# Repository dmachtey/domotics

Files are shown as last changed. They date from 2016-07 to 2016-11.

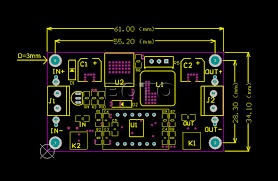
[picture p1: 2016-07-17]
electronic/board/dc-dc-converter.jpeg

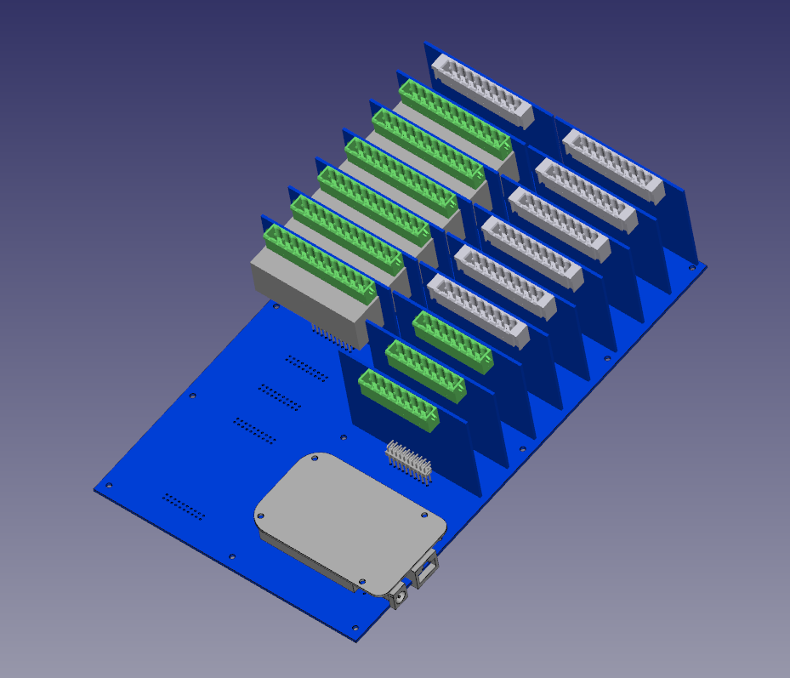
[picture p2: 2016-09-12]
pictures/3d/3d_boards_model1.png

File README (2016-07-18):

-*- mode: org -*-

* This is another domotics project
    - it is based on Beaglebone Black
    - Its able to control up to 64 Inputs or Outputs in blocks of 4
    - I've developed a main board were is possible to plug up to 16
      4-inputs or 4-outputs boards (4 GPIOs). All of them are
      optocoupled.
      - I've already developed a 4-relays board and 4-transistors
        board wich can control lights intensity by PWM and also
        4-imputs board
    - The power board can be connected to a battery and detect a mains
      failure
    - It's already able to comunicate with Openhab, an android and ios
      application
    - It's in production now since April 8th 2016 in my home
    - There is also 2 more slots with 3 and 4 analogs inputs, I'm
      planing to sense the battery level and natural light level.
    - Into one of the 16 slots I'm planing to connect some DS18B20 (up
      to 10 can be connected to one gpio) to sense the rooms
      temperatures.

* This is my first project to be published
  I'm trying to sort thins out to make them easier to understan

  I will re-write some of c++ objects to make them clear to understand

* This is what is now running
  - A full functional project is in production at my home have a look
    at the pictures folder
  - Now I'm controlling 5 PWM circuits for lights
  - I've also 5 inputs
  - All outputs are controlled by Openhab web application from LAN/WAN

* How to test this project
  - Get a Beagle bone black with Linux running
  - do :: apt-get install build-essential
  - do :: apt-get install linux-image-3.8.13-bone68 device-tree-compiler
    - to be able to compile new capes, they are needed to manage GPIOs
  - compile the cape /domotics/capes/half-in-half-pru.dts
    - copy the compiled code to /lib/firmware/
  - get yours electronics ready and connected to one of the gpio used
    on "on-production/test-pwm.cpp" like "GPIO 27"
  - Connect and input switch at "GPIO 4"
  - copy the contemns of "/domotics/on-production" to /pru2 at BBB
  - run /pru2/start.sh
  - Your led should get PWM controlled with the switch

  - Optional:
    If you want to run it with openhab for remote controll
    - Install libc-ares-dev uuid-dev libwrap0-dev libssl-dev needed by
      mosquitto library
    - Install mosquitto it can be downloaded here: http://mosquitto.org/download/
  - Install openhab, instructions at it's site: http://openhab.org/
    - copy /domotics/root/* to "/" at BBB
  - Install an configure your openhab to point to your BBB ip as http://BBBip:8080

* Project files
  - /domotics/docs/files-strucure.org

* Contact information
  - Damian Machtey
  - dmachtey at gmail com

* License
  The code and hardware is being released under GPL v3.

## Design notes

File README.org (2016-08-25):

* Why this project is different?
  - I haven't found any complete project like this, I mean a general
    purpose (home) automation project with a full developed hardware
    and software.
* This is a domotics project sw&hw (or general controller)
    - The goals of this project are:
      - to be affordable (price/(outputs + inputs)), every thing is
        hardwired (not for every one)
      - reliability (every thing have to be easy to replace, my wife
        has to be able to do it)
      - flexibility (gotten by division of GPIOs in groups of 4)
    - it is based on Beaglebone Black (BBB)
    - Its able to control up to 64 Inputs or Outputs in blocks of 4
    - I've developed a main board were is possible to plug up to 16
      4-inputs or 4-outputs boards (4 GPIOs). All of them are
      optocoupled.
      - I've already developed a 4-relays board and 4-transistors
        board wich can control lights intensity by PWM and also
        4-imputs board
    - The power board can be connected to a battery and detect a mains
      failure
    - It's already able to communicate with Openhab, an android and ios
      application, or whatever application that support MQTT protocol
    - It's in production now since April 8th 2016 in my home
    - There are also 2 more slots with 3 and 4 analogs inputs, I'm
      planing to sense the battery level and natural light level.
    - Into one of the 16 slots I'm planing to connect some DS18B20 (up
      to 10 can be connected to one gpio) to sense the rooms
      temperatures.
* This is my first project to be published
  - I'm trying to sort thins out to make them easier to understand
  - I will re-write some of c++ objects to make them more clear
  - Many directories still need to be populated,

* This is what is now running
  - A full functional project is in production at my home. Have a look
    at the pictures folder for images
  - Now I'm controlling 5 PWM circuits for lights
  - I've also 6 inputs
  - All outputs are controlled by Openhab web application from LAN/WAN

* How to test this project
  - Get a Beagle bone black with Linux running
  - to be able to compile c++ and new capes, they are needed to manage GPIOs
    - do =apt-get install build-essential=
    - do =apt-get install linux-image-3.8.13-bone68
      device-tree-compiler am335x-pru-package=
    - do =apt-get install libmosquitto-dev libmosquittopp-dev mosquitto mosquitto-clients=
  - compile the cape /domotics/capes/half-in-half-out.dts by =make=
    - install by =make install=
  - get yours electronics ready and connected to one of the gpio used
    on "running/test-pwm.cpp" like "GPIO 27"
  - Connect and input switch at "GPIO 4"
  - copy the contents of "/domotics/running" to /pru2 at BBB
  - run =make=
  - run =/pru2/start.sh=
  - Your led should get PWM controlled with the switch

  - Optional:
  - Install openhab, instructions at it's site: http://openhab.org/
    - copy /domotics/root/* to "/" at BBB
  - Install an configure your openhab to point to your BBB ip as http://BBBip:8080

* Project files
  - [[./docs/files-strucure.org]]

* Contributors
  - Every one willing to contribute with this project is welcome
** Software
   - none yet
** Electronics
   - none yet
** Linux SO
   - none yet
** Others
   - none yet

* Contact information
  - Damian Machtey
  - dmachtey at gmail com

* License
  The code and hardware is being released under GPL v3.

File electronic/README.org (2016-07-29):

   *Use kitcad to open the files*

* files structure and comments (should be here)

* Scripts/other programs
  - headers-cloner.py :: was used to automatically arrange the socket
       connectors
  - FreeRouting :: was used to help ruting
    - http://www.freerouting.net/fen/viewtopic.php?f=4&t=255

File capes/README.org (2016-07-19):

* To be able to use all the 65 gpio you need to:

** Disable some capes

edit /boot/uEnv.txt and add:
#+BEGIN_EXAMPLE
         optargs=quietcapemgr.disable_partno=BB-BONELT-HDMI,BB-BONELT-HDMIN,BB-BONE-EMMC-2G
#+END_EXAMPLE

Reboot, and

if it works: you should see some thing like this:

#+BEGIN_EXAMPLE
   root@beaglebone:~# SLOTS=/sys/devices/bone_capemgr.9/slots
   root@beaglebone:~# cat $SLOTS
    0: 54:PF---
    1: 55:PF---
    2: 56:PF---
    3: 57:PF---
    4: ff:P-O-- Bone-LT-eMMC-2G,00A0,Texas Instrument,BB-BONE-EMMC-2G
    5: ff:P-O-- Bone-Black-HDMI,00A0,Texas Instrument,BB-BONELT-HDMI
    6: ff:P-O-- Bone-Black-HDMIN,00A0,Texas Instrument,BB-BONELT-HDMIN
#+END_EXAMPLE
and ther should be no "L"  before the capes lines

** Load the new cape
As an example

#+BEGIN_SRC sh
    SLOTS=/sys/devices/bone_capemgr.9/slots
    echo half-in-half-pru > $SLOTS
#+END_SRC

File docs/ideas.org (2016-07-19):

* Some ideas to add to the system
  - Voip, can be easily added with asterisk
    - door phone to answer at cellphones
    - Gateway land line to cellphones
  - Curtain control
  - Infra red to control air conditioners & others devices
  - Temperature sensors, to measure rooms temperature

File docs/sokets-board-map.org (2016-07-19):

** Main Board GPIOs map
*** Slots
| Slot # | Order | GPIO#    | Analog=0/General=1 | G1 | G2 | GPIO_NUM |       |      |   |
|--------+-------+----------+--------------------+----+----+----------+-------+------+---|
|      0 |     4 | GPIO2_14 |                  1 |  2 | 14 |       78 |       |      |   |
|      0 |     3 | GPIO0_8  |                  1 |  0 |  8 |        8 |       |      |   |
|      0 |     2 | GPIO0_9  |                  1 |  0 |  9 |        9 |       |      |   |
|      0 |     1 | GPIO0_10 |                  1 |  0 | 10 |       10 |       |      |   |
|      1 |     4 | GPIO2_6  |                  1 |  2 |  6 |       70 |       |      |   |
|      1 |     3 | GPIO2_8  |                  1 |  2 |  8 |       72 |       |      |   |
|      1 |     2 | GPIO2_10 |                  1 |  2 | 10 |       74 |       |      |   |
|      1 |     1 | GPIO2_12 |                  1 |  2 | 12 |       76 |       |      |   |
|      2 |     4 | GPIO2_13 |                  1 |  2 | 13 |       77 |       |      |   |
|      2 |     3 | GPIO2_11 |                  1 |  2 | 11 |       75 |       |      |   |
|      2 |     2 | GPIO2_9  |                  1 |  2 |  9 |       73 |       |      |   |
|      2 |     1 | GPIO2_7  |                  1 |  2 |  7 |       71 |       |      |   |
|      3 |     4 | GPIO0_11 |                  1 |  0 | 11 |       11 |       |      |   |
|      3 |     3 | GPIO2_17 |                  1 |  2 | 17 |       81 |       |      |   |
|      3 |     2 | GPIO2_16 |                  1 |  2 | 16 |       80 |       |      |   |
|      3 |     1 | GPIO2_15 |                  1 |  2 | 15 |       79 |       |      |   |
|      4 |     4 | GPIO0_23 |                  1 |  0 | 23 |       23 |       |      |   |
|      4 |     3 | GPIO1_13 |                  1 |  1 | 13 |       45 |       |      |   |
|      4 |     2 | GPIO2_5  |                  1 |  2 |  5 |       69 |       |      |   |
|      4 |     1 | GPIO2_2  |                  1 |  2 |  2 |       66 |       |      |   |
|      5 |     4 | GPIO1_2  |                  1 |  1 |  2 |       34 |       |      |   |
|      5 |     3 | GPIO1_6  |                  1 |  1 |  6 |       38 |       |      |   |
|      5 |     2 | GPIO1_7  |                  1 |  1 |  7 |       39 |       |      |   |
|      5 |     1 | GPIO1_3  |                  1 |  1 |  3 |       35 |       |      |   |
|      6 |     4 | GPIO2_3  |                  1 |  2 |  3 |       67 |       |      |   |
|      6 |     3 | GPIO2_4  |                  1 |  2 |  4 |       68 |       |      |   |
|      6 |     2 | GPIO1_12 |                  1 |  1 | 12 |       44 |       |      |   |
|      6 |     1 | GPIO0_26 |                  1 |  0 | 26 |       26 |       |      |   |
|      7 |     4 | GPIO1_14 |                  1 |  1 | 14 |       46 |       |      |   |
|      7 |     3 | GPIO2_1  |                  1 |  2 |  1 |       65 |       |      |   |
|      7 |     2 | GPIO1_31 |                  1 |  1 | 31 |       63 | UART4 |      |   |
|      7 |     1 | GPIO1_5  |                  1 |  1 |  5 |       37 |       |      |   |
|      8 |     4 | GPIO1_1  |                  1 |  1 |  1 |       33 |       |      |   |
|      8 |     3 | GPIO1_29 |                  1 |  1 | 29 |       61 |       |      |   |
|      8 |     2 | GPIO2_24 |                  1 |  2 | 24 |       88 |       |      |   |
|      8 |     1 | GPIO2_25 |                  1 |  2 | 25 |       89 |       |      |   |
|      9 |     4 | GPIO2_23 |                  1 |  2 | 23 |       87 |       |      |   |
|      9 |     3 | GPIO2_22 |                  1 |  2 | 22 |       86 |       |      |   |
|      9 |     2 | GPIO1_0  |                  1 |  1 |  0 |       32 |       |      |   |
|      9 |     1 | GPIO1_4  |                  1 |  1 |  4 |       36 |       |      |   |
|     10 |     4 | GPIO1_30 |                  1 |  1 | 30 |       62 | UART4 |      |   |
|     10 |     3 | GPIO0_22 |                  1 |  0 | 22 |       22 |       |      |   |
|     10 |     2 | GPIO0_27 |                  1 |  0 | 27 |       27 |       |      |   |
|     10 |     1 | GPIO1_15 |                  1 |  1 | 15 |       47 |       |      |   |
|     11 |     4 | GPIO1_28 |                  1 |  1 | 28 |       60 |       |      |   |
|     11 |     3 | GPIO1_18 |                  1 |  1 | 18 |       50 |       |      |   |
|     11 |     2 | GPIO1_19 |                  1 |  1 | 19 |       51 |       |      |   |
|     11 |     1 | GPIO0_4  |                  1 |  0 |  4 |        4 | I2C1  |      |   |
|     12 |     4 | GPIO0_2  |                  1 |  0 |  2 |        2 | UART2 | I2C2 |   |
|     12 |     3 | GPIO0_15 |                  1 |  0 | 15 |       15 | UART1 | I2C1 | * |
|     12 |     2 | GPIO0_14 |                  1 |  0 | 14 |       14 | UART1 | I2C1 | * |
|     12 |     1 | GPIO3_1  |                  1 |  3 | 19 |      115 |       |      |   |
|     13 |     3 | GPIO1_16 |                  1 |  1 | 16 |       48 |       |      |   |
|     13 |     2 | GPIO0_31 |                  1 |  0 | 31 |       31 |       |      |   |
|     13 |     1 | GPIO0_30 |                  1 |  0 | 30 |       30 |       |      |   |
|     13 |     4 | GPIO0_20 |                  1 |  0 | 20 |       20 |       |      |   |
|     14 |     4 | GPIO3_21 |                  1 |  3 | 21 |      117 |       |      |   |
|     14 |     3 | GPIO1_17 |                  1 |  1 | 17 |       49 |       |      |   |
|     14 |     2 | GPIO0_3  |                  1 |  0 |  3 |        3 | UART2 | I2C2 |   |
|     14 |     1 | GPIO0_5  |                  1 |  0 |  5 |        5 | I2C1  |      |   |
|     15 |     4 | GPIO3_17 |                  1 |  3 | 17 |      113 | SPI   |      |   |
|     15 |     3 | GPIO3_16 |                  1 |  3 | 16 |      112 | SPI   |      |   |
|     15 |     2 | GPIO3_14 |                  1 |  3 | 14 |      110 | SPI   |      |   |
|     15 |     1 | GPIO3_15 |                  1 |  3 | 15 |      111 | SPI   |      |   |
|     16 |     1 | AN4      |                  0 |    |    |        0 |       |      |   |
|     16 |     2 | AN6      |                  0 |    |    |        0 |       |      |   |
|     16 |     3 | AN2      |                  0 |    |    |        0 |       |      |   |
|     16 |     4 | AN0      |                  0 |    |    |        0 |       |      |   |
|     17 |     4 | AN5      |                  0 |    |    |        0 |       |      |   |
|     17 |     3 | AN3      |                  0 |    |    |        0 |       |      |   |
|     17 |     2 | AN1      |                  0 |    |    |        0 |       |      |   |

*BBB don't boot if out-board is plug on slots 0,1,2 as [2015-10-14 Wed]*

the SYSBOOT pins, which are also the LCD_DATA pins, are located on the
headers from P8:31 to P8:46. The pins are used to index the device
table from which the list of devices is extracted.Any error that
occurs in reading the value of these pins sends the ROM boot code into
a loop, waiting for the watchdog to reset the system.

These pins can be used by software after ROM execution has
completed. So, we can't have anything connected to these pins when the
ROM code is executing.

**** Other pins functions
| I2C1_SCL  | spi0_cs0      | I2C1_SCL  | ehrpwm0_synci      | gpio0[5]  | 17 |
| I2C1_SDA  | spi0_d1       | I2C1_SDA  | ehrpwm0_tripzone   | gpio0[4]  | 18 |
| UART2_TXD | spi0_d0       | I2C2_SCL  | ehrpwm0B           | gpio0[3]  | 21 |
| UART2_RXD | spi0_sclk     | I2C2_SDA  | ehrpwm0A           | gpio0[2]  | 22 |
| UART1_TXD | uart1_txd     | dcan1_rx  | I2C1_SCL           | gpio0[15] | 24 |
| UART1_RXD | uart1_rxd     | dcan1_tx  | I2C1_SDA           | gpio0[14] | 26 |
|           |               |           |                    |           |    |
|           |               |           |                    |           |    |
| I2C2_SDA  | uart1_ctsn    | dcan0_tx  | I2C2_SDA           | gpio0[12] | 20 |
| I2C2_SCL  | uart1_rtsn    | dcan0_rx  | I2C2_SCL           | gpio0[13] | 19 |
|           |               |           |                    |           |    |

*****  I2C (from some source, not tested)
 - I2C0: used for some on-board components (HDMI, EEPROM, power
   mgmt). Not brought out to any connector/header
 - I2C2: entirely free to use, and works
 - I2C1: entirely free to use, but doesn't seem to be enabled

NOTE: In software, the busses are numbered differently; I2C2 is
identified as 1. I2C0 is identified as 0.

            |               |           |                    |           |    |
| SPI1_CS0  | mcasp0_ahclkr | spi1_cs0  | pr1_pru0_pru_r31_3 | gpio3[17] | 28 |
| SPI1_D0   | mcasp0_fsx    | spi1_d0   | pr1_pru0_pru_r31_1 | gpio3[15] | 29 |
| SPI1_D1   | mcasp0_axr0   | spi1_d1   | pr1_pru0_pru_r31_2 | gpio3[16] | 30 |
| SPI1_SCLK | mcasp0_aclkx  | spi1_sclk | pr1_pru0_pru_r31_0 | gpio3[14] | 31 |

***** SPI Definition
Serial Peripheral Interface (SPI) is a synchronous serial data
protocol used by microcontrollers for communicating with one or more
peripheral devices quickly over short distances. It can also be used
for communication between two microcontrollers.

With an SPI connection there is always one master device (usually a
microcontroller) which controls the peripheral devices. Typically
there are three lines common to all the devices:

    - MISO (Master In Slave Out) - The Slave line for sending data to
      the master,
    - MOSI (Master Out Slave In) - The Master line for sending data to
      the peripherals,
    - SCK (Serial Clock) - The clock pulses which synchronize data
      transmission generated by the master and one line specific for
      every device:
    - SS (Slave Select) - the pin on each device that the master can
      use to enable and disable specific devices.

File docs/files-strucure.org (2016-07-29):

- *bin*: The output executables go here, both for the app and for any
  tests and spikes.
- *build*: This folder contains all object files, and is removed on a
  =clean=.
- *doc*: Any notes, like my assembly notes and configuration files, are
  here. I decided to create the development and production config files
  in here instead of in a separate =config= folder as they “document”
  the configuration.
- *electronic*: All the hardware boards and related
- *include*: All project header files. All necessary third-party header
  files that do not exist under =/usr/local/include= are also placed
  here.
- *lib*: Any libs that get compiled by the project, third party or any
  needed in development. Prior to deployment, third party libraries get
  moved to =/usr/local/lib= where they belong, leaving the project
  clean enough to compile on our Linux deployment servers. I really use
  this to test different library versions than the standard.
- *pictures* project photos
- *root* configuration files that can be copied to "/" on BBB
- *running* a version that's actually running a my place
- *src*: The application and only the application's source files.
- *test*: All test code files. You do write tests, no?

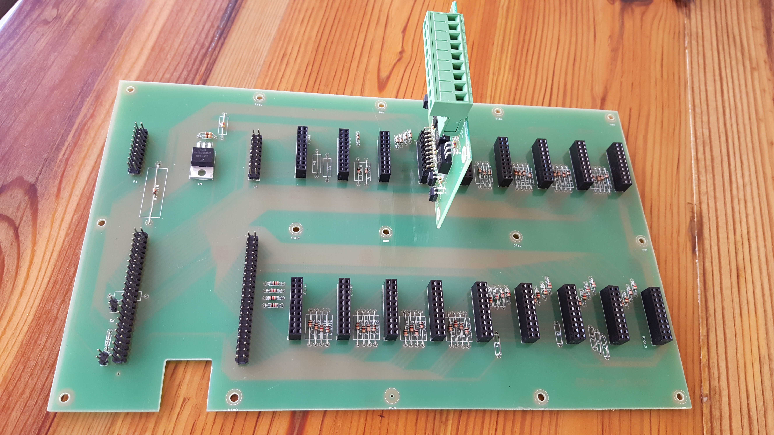
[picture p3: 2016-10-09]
pictures/main_bard_plus_out_board.jpg

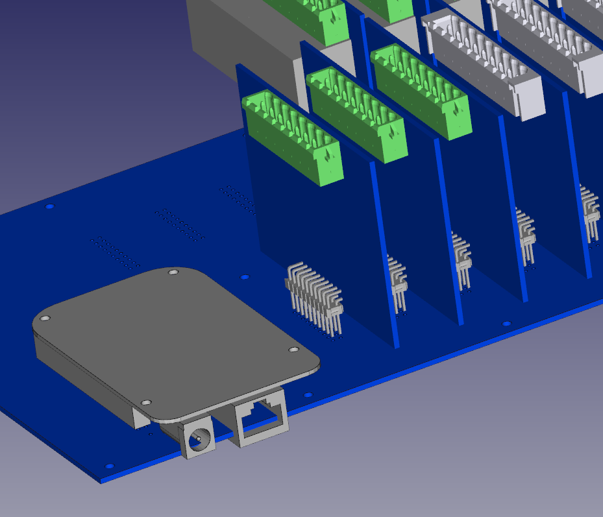
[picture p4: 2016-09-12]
pictures/3d/3d_boards_model3.png

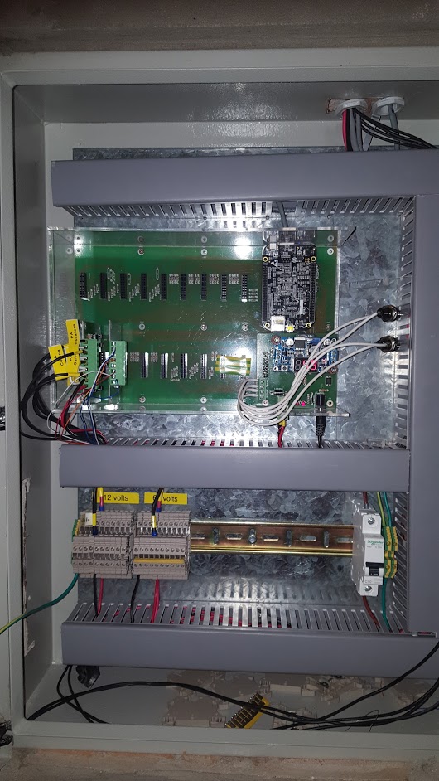
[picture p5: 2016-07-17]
pictures/on-production.jpg

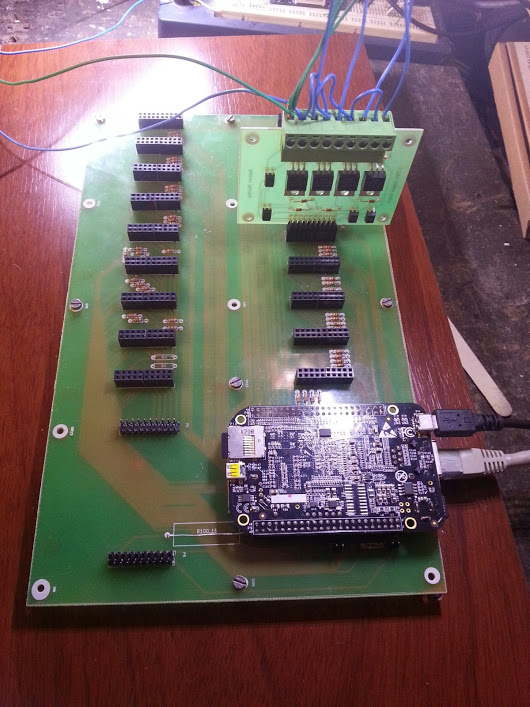
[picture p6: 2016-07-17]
pictures/main-board.jpg

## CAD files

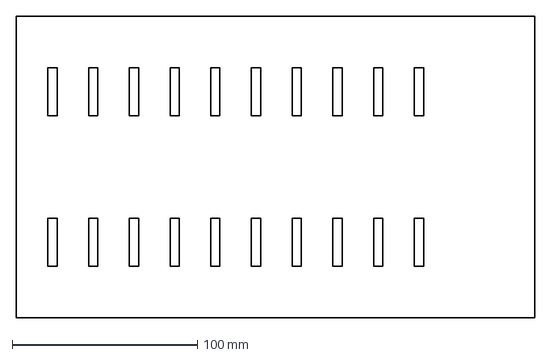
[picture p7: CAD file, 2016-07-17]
electronic/board/mb-layout.dxf
280.0 x 163.0 mm

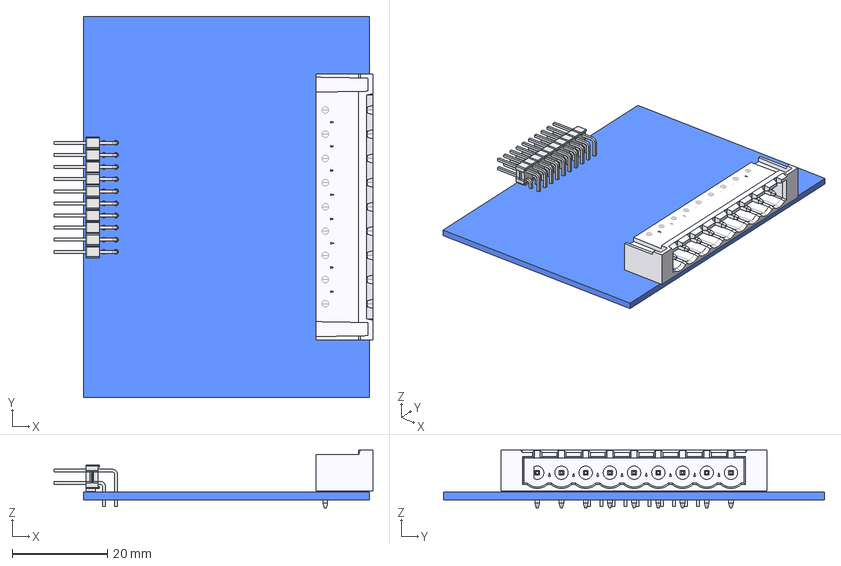
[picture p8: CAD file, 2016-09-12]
pictures/3d/out_board.FCStd
66.9 x 80.0 x 12.1 mm
Pcb
mstba_2.5-9-5.08-lr_

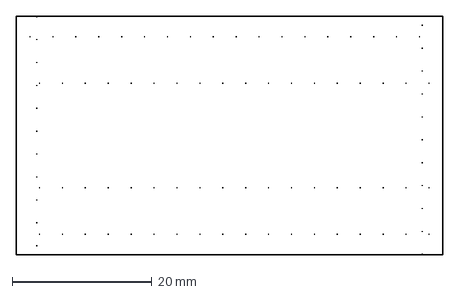
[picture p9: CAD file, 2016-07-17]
electronic/board/layout-dc-dc2.dxf
61.0 x 34.1 mm

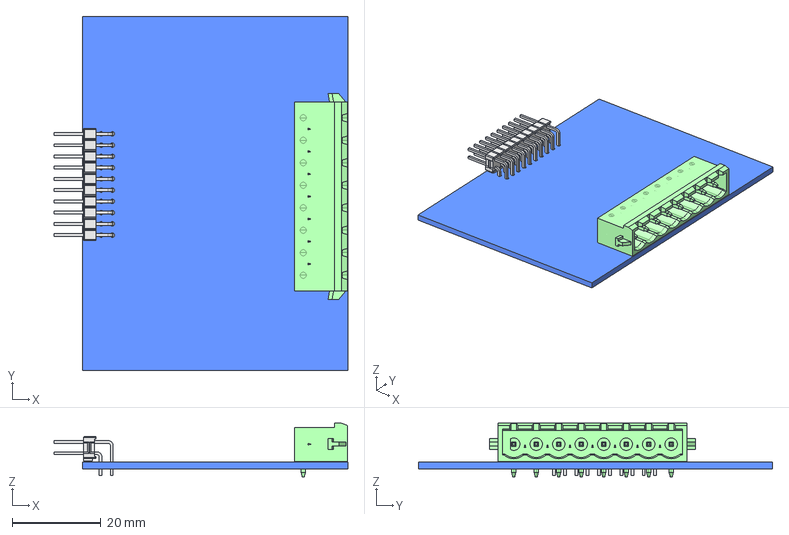
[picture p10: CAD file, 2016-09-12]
pictures/3d/in_board.FCStd
66.4 x 80.0 x 12.1 mm
Pcb
mstba_2.5-8-g-5.08-rn_EX_

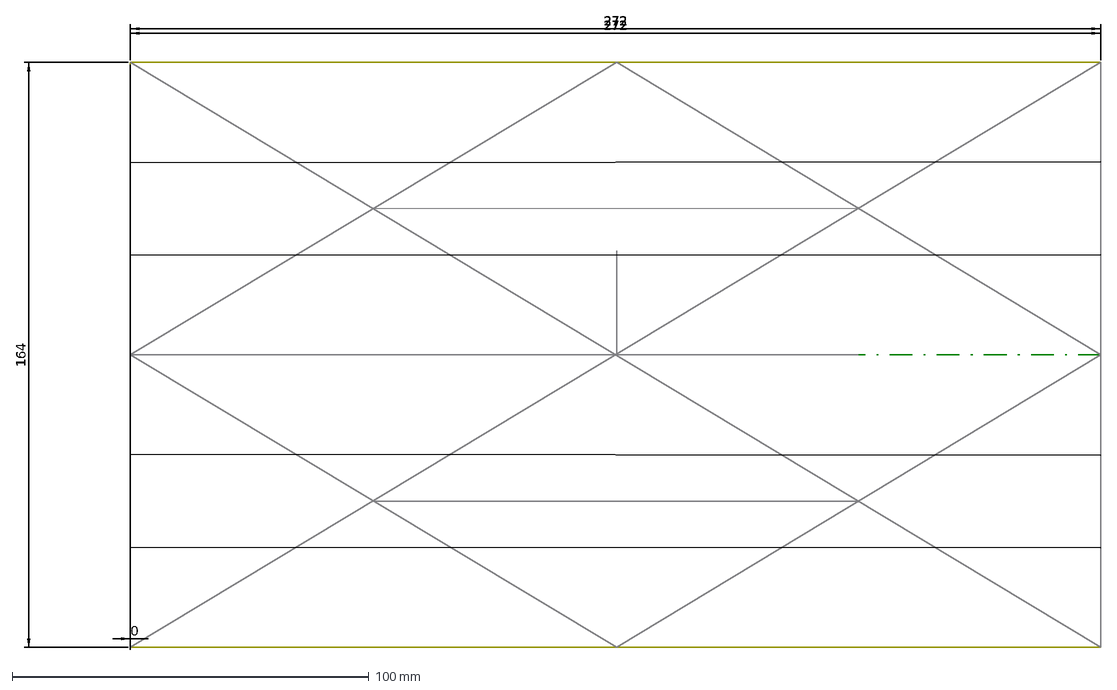
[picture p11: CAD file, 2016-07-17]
electronic/board/#mb-layout-2.dxf
272
0
164

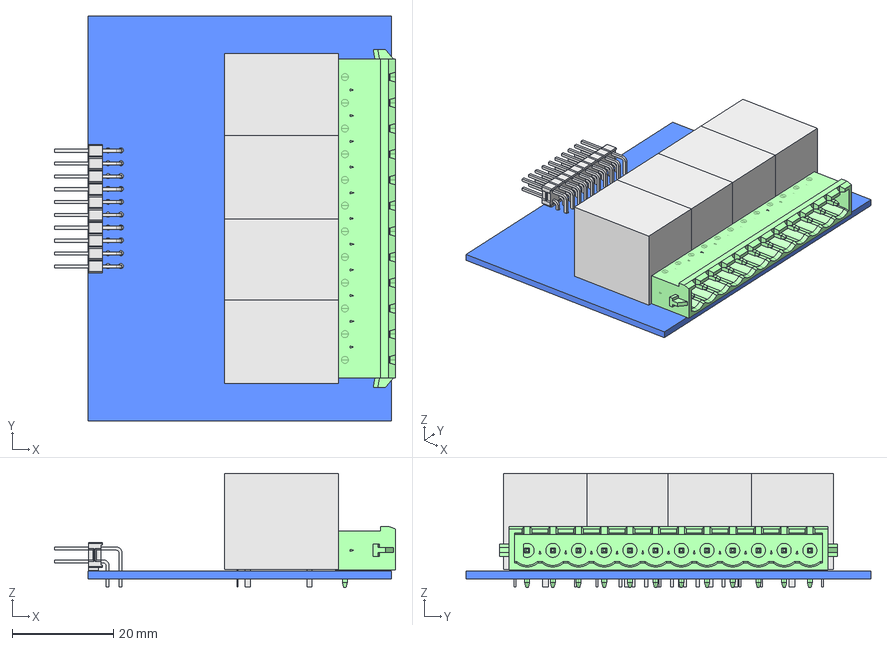
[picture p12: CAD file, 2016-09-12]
pictures/3d/relay_board.FCStd
67.4 x 80.0 x 22.6 mm
Pcb
mstba_2.5-12-g-5.08-rn_EX_

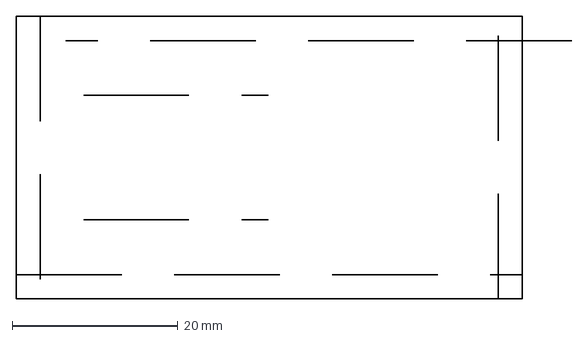
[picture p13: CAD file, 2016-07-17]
electronic/board/layout-dc-dc.dxf
66.9 x 34.1 mm

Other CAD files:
electronic/board/mb-layout-2.dxf

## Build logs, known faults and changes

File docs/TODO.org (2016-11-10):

* License
  - [X] Select a sharing license
* Electronics
  - [X] Disconnect GND from the sockets until the board has booted, to
    Avoid booting problems and lights outputs to go on during booting.
  - [ ] A fan speed control board has to be complete designed
  - [ ] Design electronics and boards for connecting *one-wire*
    temperature sensors (very simple)
  - [ ] Design electronics and board to measure battery voltage
  - [ ] Design electronics and board to measure solar light intensity
    (very simple)
  - [ ] External circuits need to be drawn

* Mechanics
  - [ ] Design a good enclosed, that allow to change boards easily
* Cape
  - [ ] left the sockets from 7 to 15 as outputs
  - [X] Do Makefile
* Clean and organize
  - [ ] Software
  - [ ] Boards
  - [ ] etc
* Software
  - [ ] Implement/test a kernel module to manage "Infra red leds" to use as
    remote control for air conditioners or other devices thought lirc
  - [ ] Improve and comment libraries
  - [X] Add an standard comment headers to all software files
  - [ ] A new calls for inputs has to be written, it has to send mqtt
    messages of it's status
  - [X] Named gpios as slots into new branch

** Add functionalists
  - [ ] At time function to switch on and off the outputs, weekly
    programs and multiple times per day
  - [ ] Need to add conscientious to objects. what are them
    controlling, what power, where are them located, how many
    circuits, to what power supply is it connected, ecc.
  - [ ] Group objects, so they can be globally controlled.

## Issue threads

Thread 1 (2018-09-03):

contacto con dmatchtey

GastonBordenabe, 2018-09-03:
Hola Damian, Soy un estudiante de programacion, de Parana. (queria comenzar un proyecto de domotica con arduino y raspery pi y _Juan Carrique_ (que es mi profesor) me dijo que me comunicara con vos) te queria comentar que me interesaria implementar tu proyecto en mi casa, pero como solo se programacion en c# y Java, mi pregunta es.... ¿vos ayudas a implementarlo? como tendria que comenzar? quizas sean muy basicas las preguntas, pero recien comienzo con esto.
(Me gusstaria ir experimentando con esto de la domotica e ir jugando/aprendiendo y quizas agregarle algunas funciones )
muchas gracias

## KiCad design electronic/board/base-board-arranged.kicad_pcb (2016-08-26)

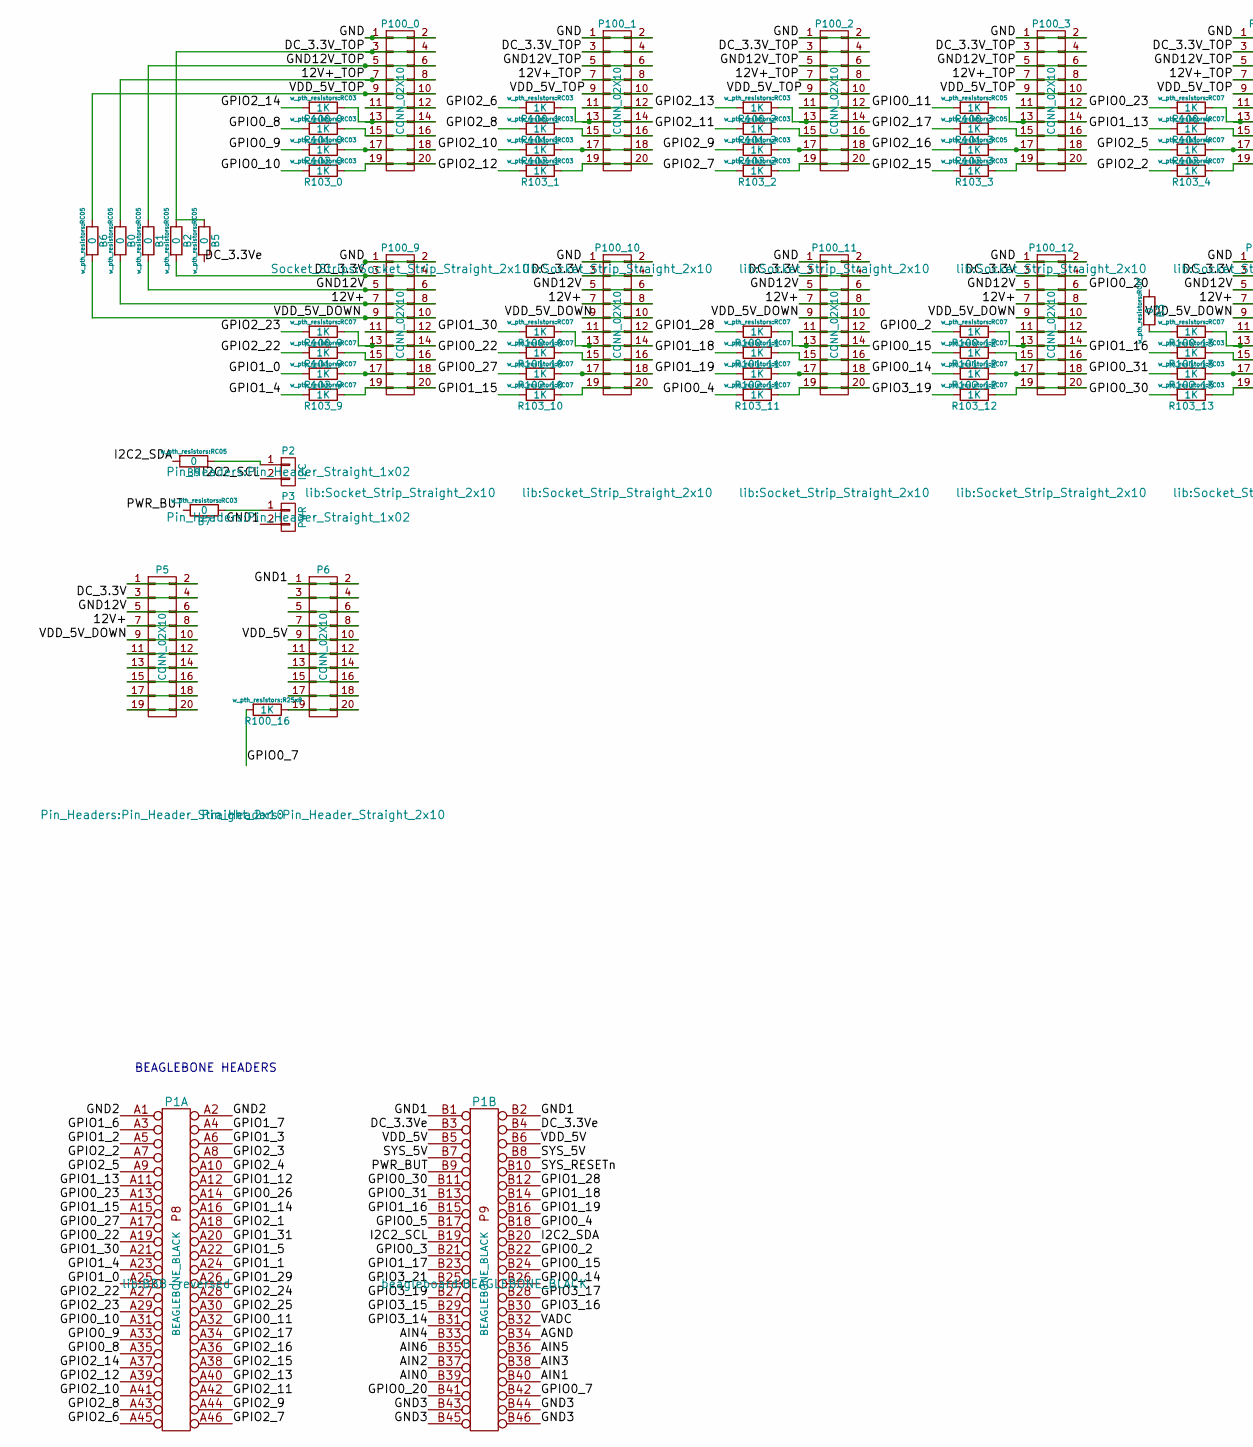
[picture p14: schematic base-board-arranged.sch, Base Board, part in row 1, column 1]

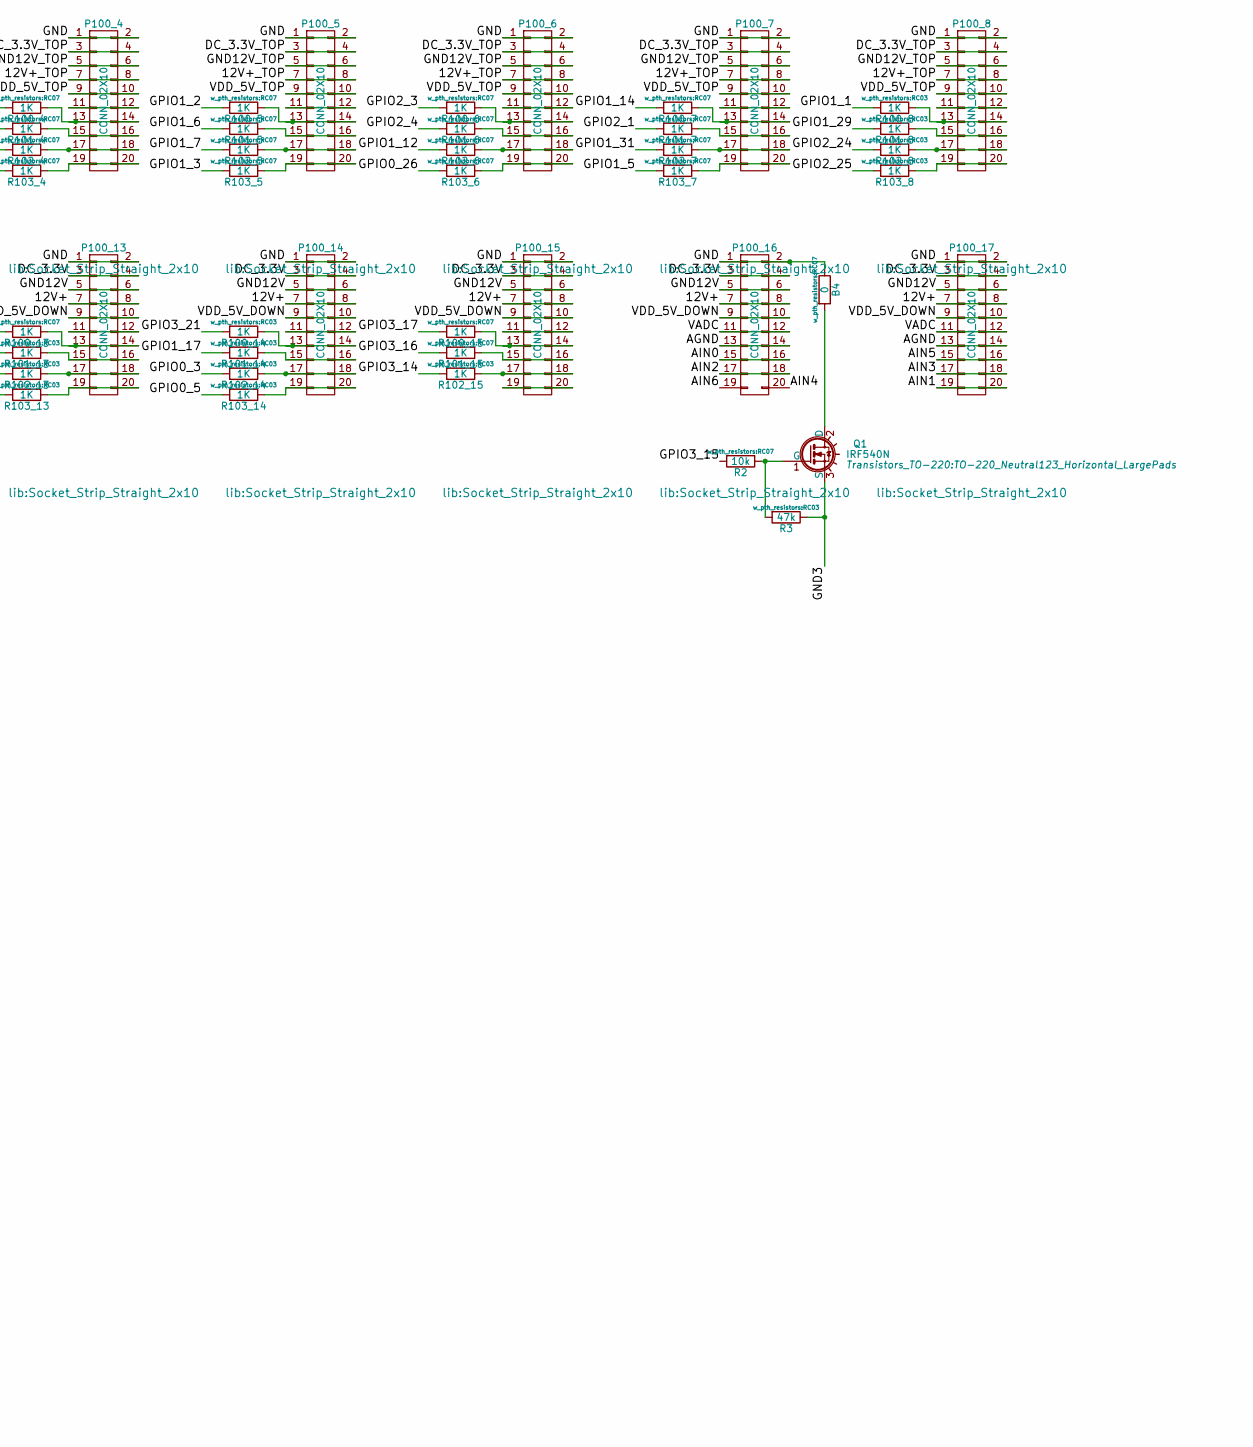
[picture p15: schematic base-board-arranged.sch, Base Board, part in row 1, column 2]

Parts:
B0, B1, B2, B5, B6, B9: 0; RC05
B3, B4: 0; RC07
B7: 0; RC03
P1: BEAGLEBONE_BLACK; BBB-reversed
P2: I2C; Pin_Header_Straight_1x02
P3: PWR; Pin_Header_Straight_1x02
P5, P6: CONN_02X10; Pin_Header_Straight_2x10
P100_0, P100_1, P100_2, P100_3, P100_4, P100_5, P100_6, P100_7, P100_8, P100_9, P100_10, P100_11, P100_12, P100_13, P100_14, P100_15, P100_16, P100_17: CONN_02X10; Socket_Strip_Straight_2x10
Q1: IRF540N; TO-220_Neutral123_Horizontal_LargePads
R2: 10k; RC07
R3: 47k; RC03
R100_0, R100_1, R100_2, R100_8, R100_14, R101_0, R101_1, R101_2, R101_8, R101_13, R101_14, R102_0, R102_1, R102_2, R102_8, R102_13, R102_14, R102_15, R103_0, R103_1, R103_2, R103_3, R103_8, R103_13, R103_14: 1K; RC03
R100_3, R101_3, R102_3: 1K; RC05
R100_4, R100_5, R100_6, R100_7, R100_9, R100_10, R100_11, R100_12, R100_13, R100_15, R101_4, R101_5, R101_6, R101_7, R101_9, R101_10, R101_11, R101_12, R101_15, R102_4, R102_5, R102_6, R102_7, R102_9, R102_10, R102_11, R102_12, R103_4, R103_5, R103_6, R103_7, R103_9, R103_10, R103_11, R103_12: 1K; RC07
R100_16: 1K; R25x8

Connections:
/12V+: B0.2, P5.7, P5.8, P100_9.7, P100_9.8, P100_10.7, P100_10.8, P100_11.7, P100_11.8, P100_12.7, P100_12.8, P100_13.7, P100_13.8, P100_14.7, P100_14.8, P100_15.7, P100_15.8, P100_16.7, P100_16.8, P100_17.7, P100_17.8
/12V+_TOP: B0.1, P100_0.7, P100_0.8, P100_1.7, P100_1.8, P100_2.7, P100_2.8, P100_3.7, P100_3.8, P100_4.7, P100_4.8, P100_5.7, P100_5.8, P100_6.7, P100_6.8, P100_7.7, P100_7.8, P100_8.7, P100_8.8
/AGND: P1.B34 (P34), P100_16.13, P100_16.14, P100_17.13, P100_17.14
/AIN0: P1.B39 (P39), P100_16.15, P100_16.16
/AIN1: P1.B40 (P40), P100_17.19, P100_17.20
/AIN2: P1.B37 (P37), P100_16.17, P100_16.18
/AIN3: P1.B38 (P38), P100_17.17, P100_17.18
/AIN4: P1.B33 (P33), P100_16.20
/AIN5: P1.B36 (P36), P100_17.15, P100_17.16
/AIN6: P1.B35 (P35), P100_16.19
/DC_3.3V: B2.2, P5.3, P5.4, P100_9.3, P100_9.4, P100_10.3, P100_10.4, P100_11.3, P100_11.4, P100_12.3, P100_12.4, P100_13.3, P100_13.4, P100_14.3, P100_14.4, P100_15.3, P100_15.4, P100_16.3, P100_16.4, P100_17.3, P100_17.4
/DC_3.3V_TOP: B2.1, B5.1, P100_0.3, P100_0.4, P100_1.3, P100_1.4, P100_2.3, P100_2.4, P100_3.3, P100_3.4, P100_4.3, P100_4.4, P100_5.3, P100_5.4, P100_6.3, P100_6.4, P100_7.3, P100_7.4, P100_8.3, P100_8.4
/DC_3.3Ve: B5.2, P1.B3, P1.B4 (P4)
/GND: B4.1, P100_0.1, P100_0.2, P100_1.1, P100_1.2, P100_2.1, P100_2.2, P100_3.1, P100_3.2, P100_4.1, P100_4.2, P100_5.1, P100_5.2, P100_6.1, P100_6.2, P100_7.1, P100_7.2, P100_8.1, P100_8.2, P100_9.1, P100_9.2, P100_10.1, P100_10.2, P100_11.1, P100_11.2, P100_12.1, P100_12.2, P100_13.1, P100_13.2, P100_14.1, P100_14.2, P100_15.1, P100_15.2, P100_16.1, P100_16.2, P100_17.1, P100_17.2
/GND1: P1.B1 (GND), P1.B2 (P2), P3.2, P6.1, P6.2
/GND2: P1.A1 (GND), P1.A2 (P2)
/GND3: P1.B43 (P43), P1.B44 (P44), P1.B45 (P45), P1.B46 (P46), Q1.3 (S), R3.1
/GND12V: B1.2, P5.5, P5.6, P100_9.5, P100_9.6, P100_10.5, P100_10.6, P100_11.5, P100_11.6, P100_12.5, P100_12.6, P100_13.5, P100_13.6, P100_14.5, P100_14.6, P100_15.5, P100_15.6, P100_16.5, P100_16.6, P100_17.5, P100_17.6
/GND12V_TOP: B1.1, P100_0.5, P100_0.6, P100_1.5, P100_1.6, P100_2.5, P100_2.6, P100_3.5, P100_3.6, P100_4.5, P100_4.6, P100_5.5, P100_5.6, P100_6.5, P100_6.6, P100_7.5, P100_7.6, P100_8.5, P100_8.6
/GPIO0_2: P1.B22 (P22), R100_12.2
/GPIO0_3: P1.B21 (P21), R102_14.2
/GPIO0_4: P1.B18 (P18), R103_11.2
/GPIO0_5: P1.B17 (P17), R103_14.2
/GPIO0_7: P1.B42 (P42), R100_16.2
/GPIO0_8: P1.A35 (P35), R101_0.2
/GPIO0_9: P1.A33 (P33), R102_0.2
/GPIO0_10: P1.A31 (P31), R103_0.2
/GPIO0_11: P1.A32 (P32), R100_3.2
/GPIO0_14: P1.B26 (P26), R102_12.2
/GPIO0_15: P1.B24 (P24), R101_12.2
/GPIO0_20: B3.1, P1.B41 (P41)
/GPIO0_22: P1.A19 (P19), R101_10.2
/GPIO0_23: P1.A13 (P13), R100_4.2
/GPIO0_26: P1.A14 (P14), R103_6.2
/GPIO0_27: P1.A17 (P17), R102_10.2
/GPIO0_30: P1.B11, R103_13.2
/GPIO0_31: P1.B13 (P13), R102_13.2
/GPIO1_0: P1.A25 (P25), R102_9.2
/GPIO1_1: P1.A24 (P24), R100_8.2
/GPIO1_2: P1.A5 (P5), R100_5.2
/GPIO1_3: P1.A6 (P6), R103_5.2
/GPIO1_4: P1.A23 (P23), R103_9.2
/GPIO1_5: P1.A22 (P22), R103_7.2
/GPIO1_6: P1.A3 (P3), R101_5.2
/GPIO1_7: P1.A4 (P4), R102_5.2
/GPIO1_12: P1.A12 (P12), R102_6.2
/GPIO1_13: P1.A11 (P11), R101_4.2
/GPIO1_14: P1.A16 (P16), R100_7.2
/GPIO1_15: P1.A15 (P15), R103_10.2
/GPIO1_16: P1.B15 (P15), R101_13.2
/GPIO1_17: P1.B23 (P23), R101_14.2
/GPIO1_18: P1.B14 (P14), R101_11.2
/GPIO1_19: P1.B16 (P16), R102_11.2
/GPIO1_28: P1.B12 (P12), R100_11.2
/GPIO1_29: P1.A26 (P26), R101_8.2
/GPIO1_30: P1.A21 (P21), R100_10.2
/GPIO1_31: P1.A20 (P20), R102_7.2
/GPIO2_1: P1.A18 (P18), R101_7.2
/GPIO2_2: P1.A7 (P7), R103_4.2
/GPIO2_3: P1.A8 (P8), R100_6.2
/GPIO2_4: P1.A10 (P10), R101_6.2
/GPIO2_5: P1.A9 (P9), R102_4.2
/GPIO2_6: P1.A45 (P45), R100_1.2
/GPIO2_7: P1.A46 (P46), R103_2.2
/GPIO2_8: P1.A43 (P43), R101_1.2
/GPIO2_9: P1.A44 (P44), R102_2.2
/GPIO2_10: P1.A41 (P41), R102_1.2
/GPIO2_11: P1.A42 (P42), R101_2.2
/GPIO2_12: P1.A39 (P39), R103_1.2
/GPIO2_13: P1.A40 (P40), R100_2.2
/GPIO2_14: P1.A37 (P37), R100_0.2
/GPIO2_15: P1.A38 (P38), R103_3.2
/GPIO2_16: P1.A36 (P36), R102_3.2
/GPIO2_17: P1.A34 (P34), R101_3.2
/GPIO2_22: P1.A27 (P27), R101_9.2
/GPIO2_23: P1.A29 (P29), R100_9.2
/GPIO2_24: P1.A28 (AP28), R102_8.2
/GPIO2_25: P1.A30 (P30), R103_8.2
/GPIO3_14: P1.B31 (P31), R102_15.2
/GPIO3_15: P1.B29 (P29), R2.2
/GPIO3_16: P1.B30 (P30), R101_15.2
/GPIO3_17: P1.B28 (AP28), R100_15.2
/GPIO3_19: P1.B27 (P27), R103_12.2
/GPIO3_21: P1.B25 (P25), R100_14.2
/I2C2_SCL: P1.B19 (P19), P2.2
/I2C2_SDA: B9.2, P1.B20 (P20)
/PWR_BUT: B7.2, P1.B9 (P9)
/SYS_5V: P1.B7 (P7), P1.B8 (P8)
/SYS_RESETn: P1.B10 (P10)
/VADC: P1.B32 (P32), P100_16.11, P100_16.12, P100_17.11, P100_17.12
/VDD_5V: P1.B5 (P5), P1.B6 (P6), P6.9, P6.10
/VDD_5V_DOWN: B6.2, P5.9, P5.10, P100_9.9, P100_9.10, P100_10.9, P100_10.10, P100_11.9, P100_11.10, P100_12.9, P100_12.10, P100_13.9, P100_13.10, P100_14.9, P100_14.10, P100_15.9, P100_15.10, P100_16.9, P100_16.10, P100_17.9, P100_17.10
/VDD_5V_TOP: B6.1, P100_0.9, P100_0.10, P100_1.9, P100_1.10, P100_2.9, P100_2.10, P100_3.9, P100_3.10, P100_4.9, P100_4.10, P100_5.9, P100_5.10, P100_6.9, P100_6.10, P100_7.9, P100_7.10, P100_8.9, P100_8.10
unnamed: B3.2, R100_13.2
unnamed: B4.2, Q1.2 (D)
unnamed: B7.1, P3.1
unnamed: B9.1, P2.1
unnamed: P5.1, P5.2
unnamed: P5.11, P5.12
unnamed: P5.13, P5.14
unnamed: P5.15, P5.16
unnamed: P5.17, P5.18
unnamed: P5.19, P5.20
unnamed: P6.3, P6.4
unnamed: P6.5, P6.6
unnamed: P6.7, P6.8
unnamed: P6.11, P6.12
unnamed: P6.13, P6.14
unnamed: P6.15, P6.16
unnamed: P6.17, P6.18
unnamed: P6.19, P6.20, R100_16.1
unnamed: P100_0.11, P100_0.12
unnamed: P100_0.13, P100_0.14, R100_0.1
unnamed: P100_0.15, P100_0.16, R101_0.1
unnamed: P100_0.17, P100_0.18, R102_0.1
unnamed: P100_0.19, P100_0.20, R103_0.1
unnamed: P100_1.11, P100_1.12
unnamed: P100_1.13, P100_1.14, R100_1.1
unnamed: P100_1.15, P100_1.16, R101_1.1
unnamed: P100_1.17, P100_1.18, R102_1.1
unnamed: P100_1.19, P100_1.20, R103_1.1
unnamed: P100_2.11, P100_2.12
unnamed: P100_2.13, P100_2.14, R100_2.1
unnamed: P100_2.15, P100_2.16, R101_2.1
unnamed: P100_2.17, P100_2.18, R102_2.1
unnamed: P100_2.19, P100_2.20, R103_2.1
unnamed: P100_3.11, P100_3.12
unnamed: P100_3.13, P100_3.14, R100_3.1
unnamed: P100_3.15, P100_3.16, R101_3.1
unnamed: P100_3.17, P100_3.18, R102_3.1
unnamed: P100_3.19, P100_3.20, R103_3.1
unnamed: P100_4.11, P100_4.12
unnamed: P100_4.13, P100_4.14, R100_4.1
unnamed: P100_4.15, P100_4.16, R101_4.1
unnamed: P100_4.17, P100_4.18, R102_4.1
unnamed: P100_4.19, P100_4.20, R103_4.1
unnamed: P100_5.11, P100_5.12
unnamed: P100_5.13, P100_5.14, R100_5.1
unnamed: P100_5.15, P100_5.16, R101_5.1
unnamed: P100_5.17, P100_5.18, R102_5.1
unnamed: P100_5.19, P100_5.20, R103_5.1
unnamed: P100_6.11, P100_6.12
unnamed: P100_6.13, P100_6.14, R100_6.1
unnamed: P100_6.15, P100_6.16, R101_6.1
unnamed: P100_6.17, P100_6.18, R102_6.1
unnamed: P100_6.19, P100_6.20, R103_6.1
unnamed: P100_7.11, P100_7.12
unnamed: P100_7.13, P100_7.14, R100_7.1
unnamed: P100_7.15, P100_7.16, R101_7.1
unnamed: P100_7.17, P100_7.18, R102_7.1
unnamed: P100_7.19, P100_7.20, R103_7.1
unnamed: P100_8.11, P100_8.12
unnamed: P100_8.13, P100_8.14, R100_8.1
unnamed: P100_8.15, P100_8.16, R101_8.1
unnamed: P100_8.17, P100_8.18, R102_8.1
unnamed: P100_8.19, P100_8.20, R103_8.1
unnamed: P100_9.11, P100_9.12
unnamed: P100_9.13, P100_9.14, R100_9.1
unnamed: P100_9.15, P100_9.16, R101_9.1
unnamed: P100_9.17, P100_9.18, R102_9.1
unnamed: P100_9.19, P100_9.20, R103_9.1
unnamed: P100_10.11, P100_10.12
unnamed: P100_10.13, P100_10.14, R100_10.1
unnamed: P100_10.15, P100_10.16, R101_10.1
unnamed: P100_10.17, P100_10.18, R102_10.1
unnamed: P100_10.19, P100_10.20, R103_10.1
unnamed: P100_11.11, P100_11.12
unnamed: P100_11.13, P100_11.14, R100_11.1
unnamed: P100_11.15, P100_11.16, R101_11.1
unnamed: P100_11.17, P100_11.18, R102_11.1
unnamed: P100_11.19, P100_11.20, R103_11.1
unnamed: P100_12.11, P100_12.12
unnamed: P100_12.13, P100_12.14, R100_12.1
unnamed: P100_12.15, P100_12.16, R101_12.1
unnamed: P100_12.17, P100_12.18, R102_12.1
unnamed: P100_12.19, P100_12.20, R103_12.1
unnamed: P100_13.11, P100_13.12
unnamed: P100_13.13, P100_13.14, R100_13.1
unnamed: P100_13.15, P100_13.16, R101_13.1
unnamed: P100_13.17, P100_13.18, R102_13.1
unnamed: P100_13.19, P100_13.20, R103_13.1
unnamed: P100_14.11, P100_14.12
unnamed: P100_14.13, P100_14.14, R100_14.1
unnamed: P100_14.15, P100_14.16, R101_14.1
unnamed: P100_14.17, P100_14.18, R102_14.1
unnamed: P100_14.19, P100_14.20, R103_14.1
unnamed: P100_15.11, P100_15.12
unnamed: P100_15.13, P100_15.14, R100_15.1
unnamed: P100_15.15, P100_15.16, R101_15.1
unnamed: P100_15.17, P100_15.18, R102_15.1
unnamed: P100_15.19, P100_15.20
unnamed: Q1.1 (G), R2.1, R3.2

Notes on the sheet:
BEAGLEBONE HEADERS

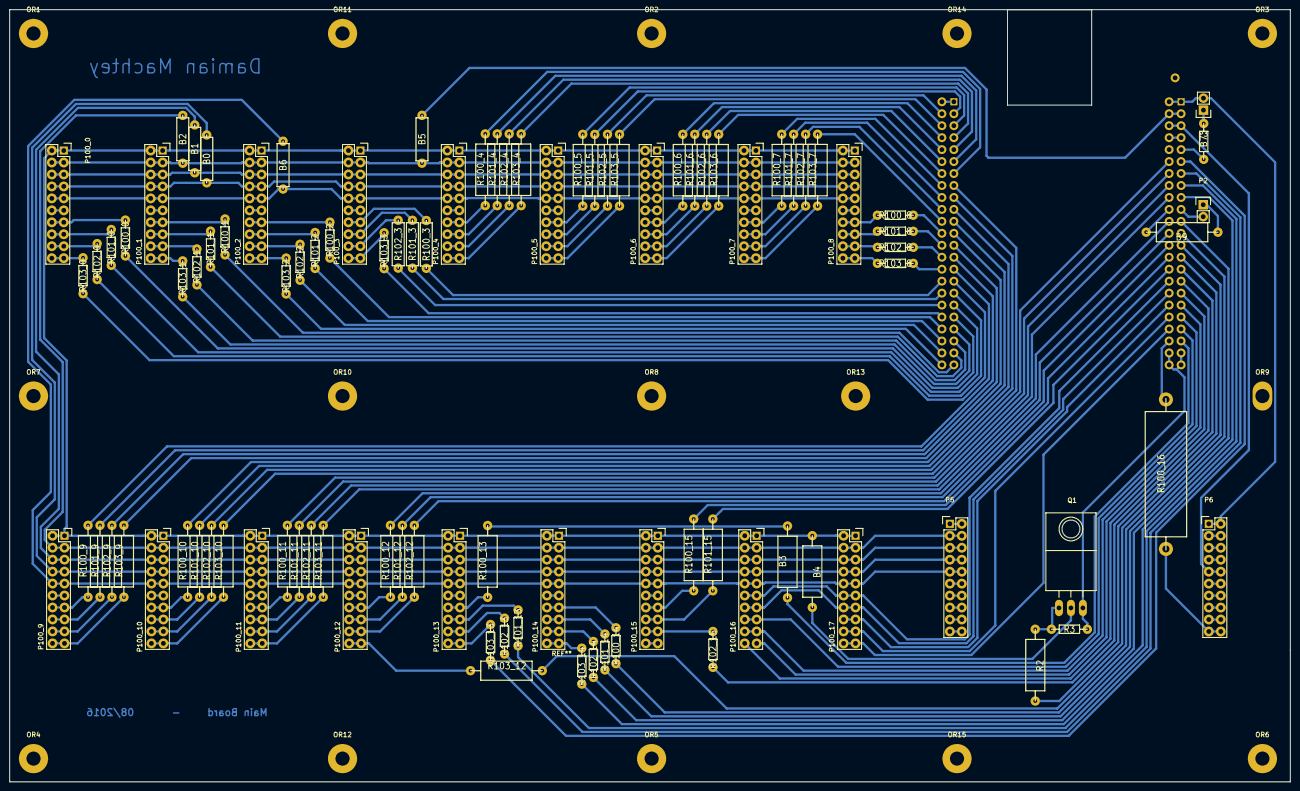
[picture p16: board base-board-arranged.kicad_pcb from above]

Board: 2 copper layers, 272.0 x 164.0 mm, 114 parts (0 on the bottom side), 191 nets.

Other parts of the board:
OR1, OR2, OR3, OR4, OR5, OR6, OR7, OR8, OR9, OR10, OR11, OR12, OR13, OR14, OR15: Fix Hole; SolderWirePad_single_2-5mmDrill

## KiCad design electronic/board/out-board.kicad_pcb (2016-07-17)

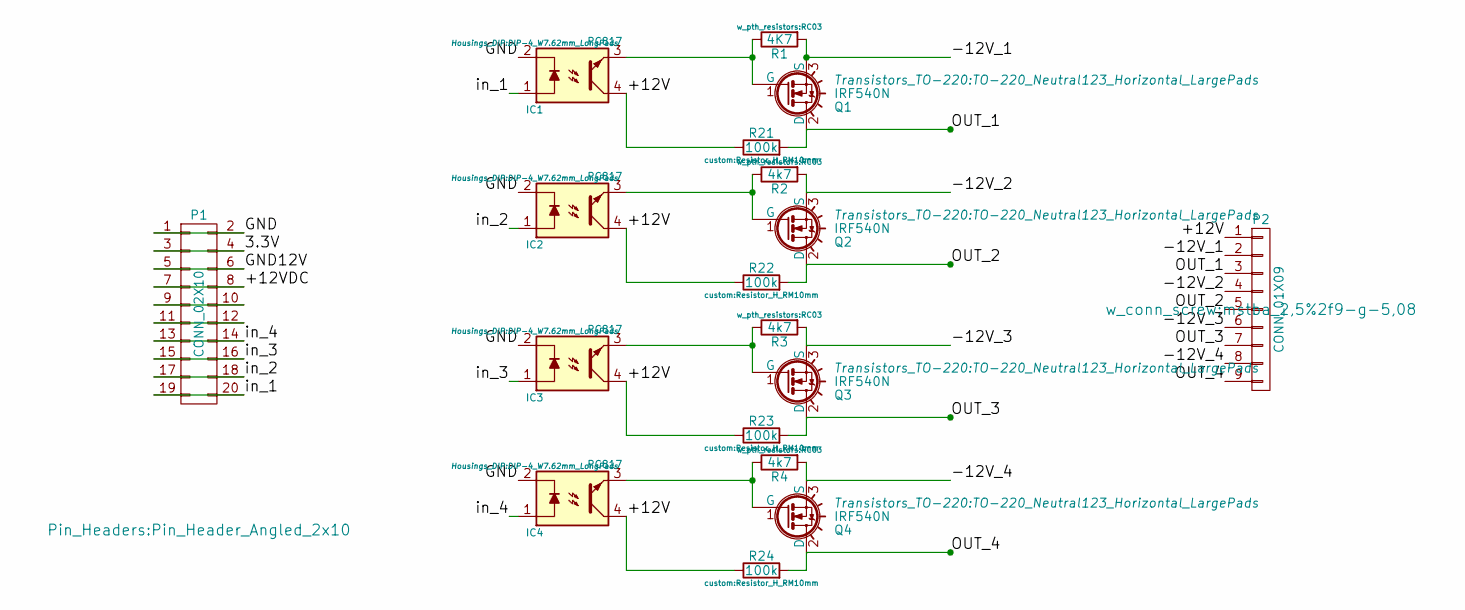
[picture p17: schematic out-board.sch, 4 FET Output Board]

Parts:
IC1, IC2, IC3, IC4: PC817; DIP-4_W7.62mm_LongPads
P1: CONN_02X10; Pin_Header_Angled_2x10
P2: CONN_01X09; mstba_2,5%2f9-g-5,08
Q1, Q2, Q3, Q4: IRF540N; TO-220_Neutral123_Horizontal_LargePads
R1: 4K7; RC03
R2, R3, R4: 4k7; RC03
R21, R22, R23, R24: 100k; Resistor_H_RM10mm

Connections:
/3.3V: P1.3, P1.4
/+12V: IC1.4, IC2.4, IC3.4, IC4.4, P2.1, R21.1, R22.1, R23.1, R24.1
/+12VDC: P1.7, P1.8
/-12V_1: P2.2, Q1.3 (S), R1.2
/-12V_2: P2.4, Q2.3 (S), R2.2
/-12V_3: P2.6, Q3.3 (S), R3.2
/-12V_4: P2.8, Q4.3 (S), R4.2
/GND: IC1.2, IC2.2, IC3.2, IC4.2, P1.1, P1.2
/GND12V: P1.5, P1.6
/OUT_1: P2.3, Q1.2 (D), R21.2
/OUT_2: P2.5, Q2.2 (D), R22.2
/OUT_3: P2.7, Q3.2 (D), R23.2
/OUT_4: P2.9, Q4.2 (D), R24.2
/in_1: IC1.1, P1.19, P1.20
/in_2: IC2.1, P1.17, P1.18
/in_3: IC3.1, P1.15, P1.16
/in_4: IC4.1, P1.13, P1.14
unnamed: IC1.3, Q1.1 (G), R1.1
unnamed: IC2.3, Q2.1 (G), R2.1
unnamed: IC3.3, Q3.1 (G), R3.1
unnamed: IC4.3, Q4.1 (G), R4.1
unnamed: P1.9, P1.10
unnamed: P1.11, P1.12

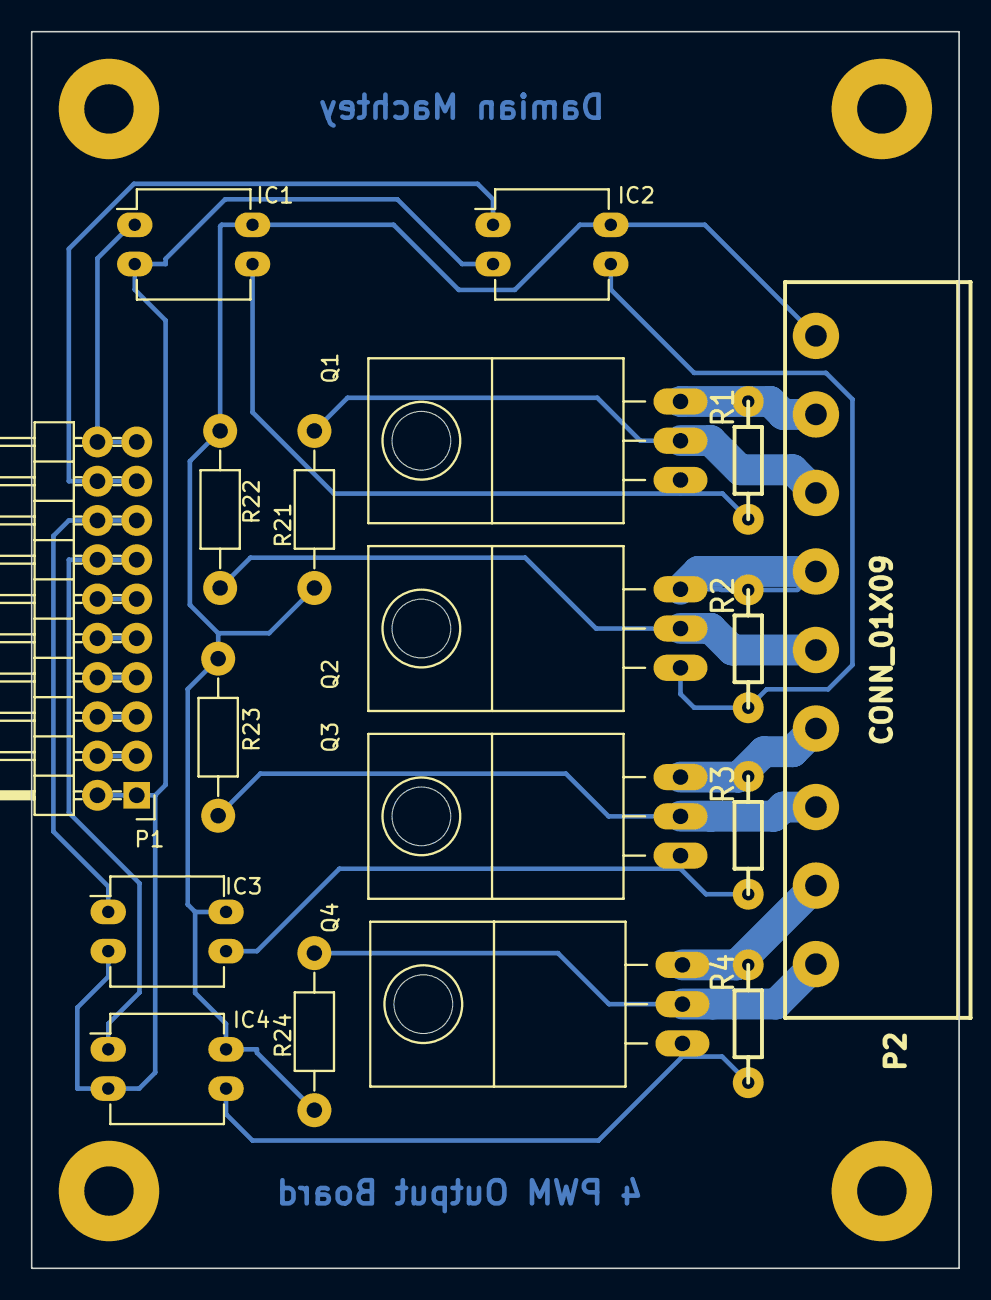
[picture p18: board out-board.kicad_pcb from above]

Board: 2 copper layers, 60.0 x 80.0 mm, 22 parts (0 on the bottom side), 23 nets.

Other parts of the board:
OR1, OR2, OR3, OR4: SolderWirePad_single_2-5mmDrill

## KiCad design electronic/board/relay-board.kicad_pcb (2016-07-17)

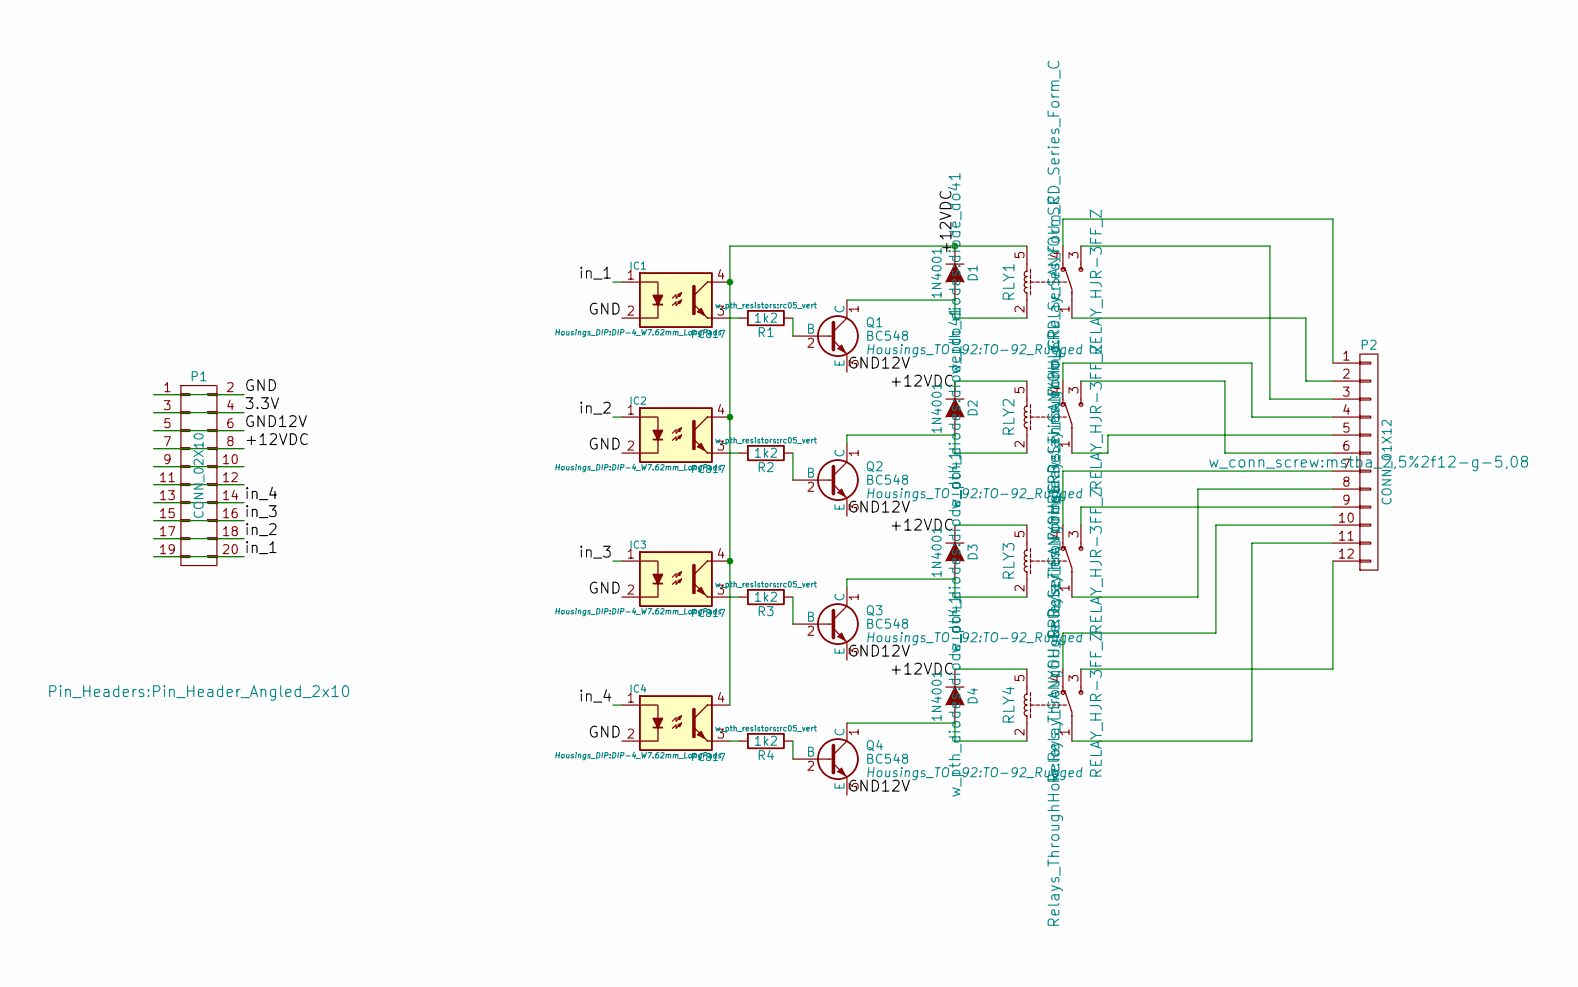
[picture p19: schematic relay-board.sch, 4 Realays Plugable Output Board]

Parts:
D1, D2, D3, D4: 1N4001; diode_do41
IC1, IC2, IC3, IC4: PC817; DIP-4_W7.62mm_LongPads
P1: CONN_02X10; Pin_Header_Angled_2x10
P2: CONN_01X12; mstba_2,5%2f12-g-5,08
Q1, Q2, Q3, Q4: BC548; TO-92_Rugged
R1, R2, R3, R4: 1k2; rc05_vert
RLY1, RLY2, RLY3, RLY4: RELAY_HJR-3FF_Z; Relay_SANYOU_SRD_Series_Form_C

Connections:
/3.3V: P1.3, P1.4
/+12VDC: D2.1 (K), P1.7, P1.8, RLY2.5
/GND: IC1.2, IC2.2, IC3.2, IC4.2, P1.1, P1.2
/GND12V: P1.5, P1.6, Q1.3 (E), Q2.3 (E), Q3.3 (E), Q4.3 (E)
/in_1: IC1.1, P1.19, P1.20
/in_2: IC2.1, P1.17, P1.18
/in_3: IC3.1, P1.15, P1.16
/in_4: IC4.1, P1.13, P1.14
unnamed: D1.1 (K), IC1.4, IC2.4, IC3.4, IC4.4, RLY1.5
unnamed: D1.2 (A), Q1.1 (C), RLY1.2
unnamed: D2.2 (A), Q2.1 (C), RLY2.2
unnamed: D3.1 (K), RLY3.5
unnamed: D3.2 (A), Q3.1 (C), RLY3.2
unnamed: D4.1 (K), RLY4.5
unnamed: D4.2 (A), Q4.1 (C), RLY4.2
unnamed: IC1.3, R1.2
unnamed: IC2.3, R2.2
unnamed: IC3.3, R3.2
unnamed: IC4.3, R4.2
unnamed: P1.9, P1.10
unnamed: P1.11, P1.12
unnamed: P2.1, RLY1.4
unnamed: P2.2, RLY1.1
unnamed: P2.3, RLY1.3
unnamed: P2.4, RLY2.4
unnamed: P2.5, RLY2.1
unnamed: P2.6, RLY2.3
unnamed: P2.7, RLY3.4
unnamed: P2.8, RLY3.1
unnamed: P2.9, RLY3.3
unnamed: P2.10, RLY4.4
unnamed: P2.11, RLY4.1
unnamed: P2.12, RLY4.3
unnamed: Q1.2 (B), R1.1
unnamed: Q2.2 (B), R2.1
unnamed: Q3.2 (B), R3.1
unnamed: Q4.2 (B), R4.1

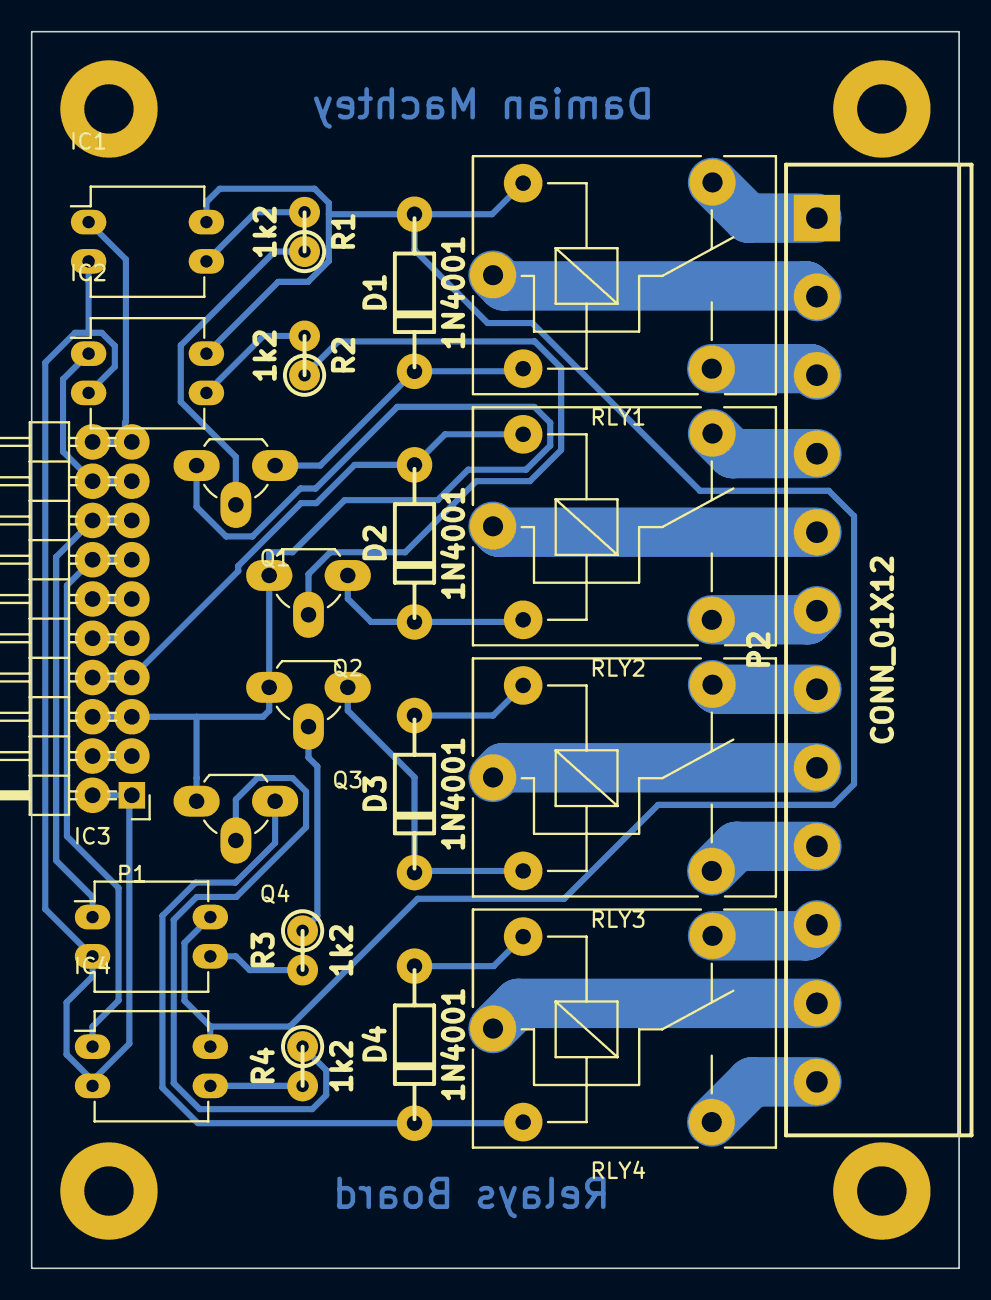
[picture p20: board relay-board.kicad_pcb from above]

Board: 2 copper layers, 60.0 x 80.0 mm, 26 parts (0 on the bottom side), 37 nets.

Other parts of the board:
OR1, OR2, OR3, OR4: SolderWirePad_single_2-5mmDrill

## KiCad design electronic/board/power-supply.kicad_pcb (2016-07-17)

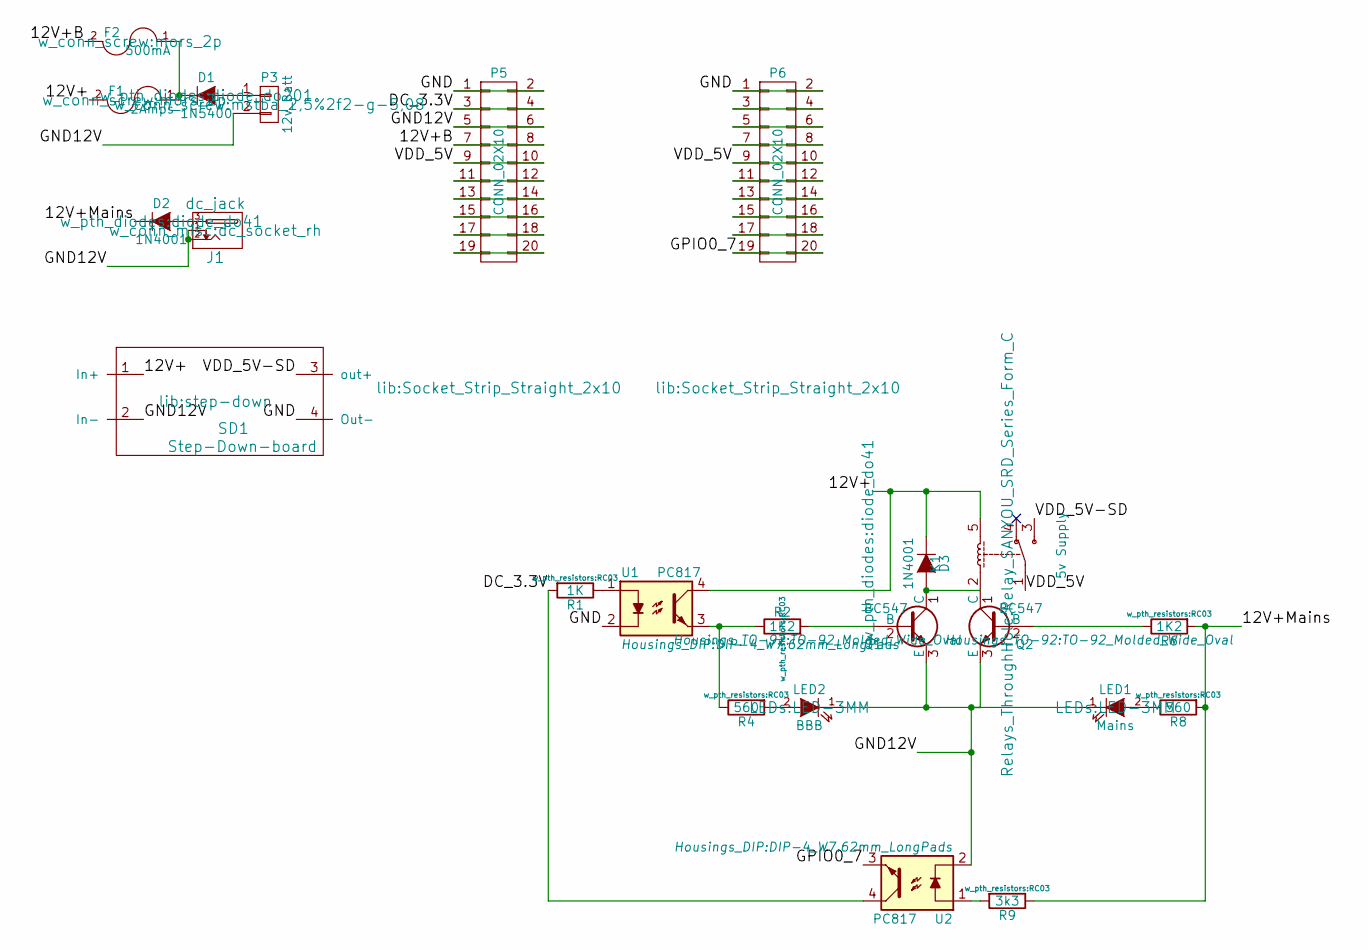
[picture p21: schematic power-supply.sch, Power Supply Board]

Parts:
D1: 1N5400; diode_do201
D2, D3: 1N4001; diode_do41
F1: 2Amps; mors_2p
F2: 500mA; mors_2p
J1: dc_jack; dc_socket_rh
K1: 5v Supply; Relay_SANYOU_SRD_Series_Form_C
LED1: Mains; LED-3MM
LED2: BBB; LED-3MM
P3: 12v_Batt; mstba_2,5%2f2-g-5,08
P5, P6: CONN_02X10; Socket_Strip_Straight_2x10
Q1, Q2: BC547; TO-92_Molded_Wide_Oval
R1: 1K; RC03
R2, R6: 1K2; RC03
R4, R8: 560; RC03
R9: 3k3; RC03
SD1: Step-Down-board; step-down
U1, U2: PC817; DIP-4_W7.62mm_LongPads

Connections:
/12V+: D3.1 (K), F1.2, K1.5, SD1.1 (In+), U1.4
/12V+B: F2.2, P5.7, P5.8
/12V+Mains: D2.1 (K), R6.2, R8.2, R9.1
/DC_3.3V: P5.3, P5.4, R1.2, U2.4
/GND: P5.1, P5.2, P6.1, P6.2, SD1.4 (Out-), U1.2
/GND12V: J1.1, J1.2, LED1.1 (K), LED2.1 (K), P3.2, P5.5, P5.6, Q1.3 (E), Q2.3 (E), SD1.2 (In-), U2.2
/GPIO0_7: P6.19, P6.20, U2.3
/VDD_5V: K1.1, P5.9, P5.10, P6.9, P6.10
/VDD_5V-SD: K1.3, SD1.3 (out+)
unnamed: D1.1 (K), F1.1, F2.1
unnamed: D1.2 (A), P3.1
unnamed: D2.2 (A), J1.3
unnamed: D3.2 (A), K1.2, Q1.1 (C), Q2.1 (C)
unnamed: LED1.2 (A), R8.1
unnamed: LED2.2 (A), R4.2
unnamed: P5.11, P5.12
unnamed: P5.13, P5.14
unnamed: P5.15, P5.16
unnamed: P5.17, P5.18
unnamed: P5.19, P5.20
unnamed: P6.3, P6.4
unnamed: P6.5, P6.6
unnamed: P6.7, P6.8
unnamed: P6.11, P6.12
unnamed: P6.13, P6.14
unnamed: P6.15, P6.16
unnamed: P6.17, P6.18
unnamed: Q1.2 (B), R2.2
unnamed: Q2.2 (B), R6.1
unnamed: R1.1, U1.1
unnamed: R2.1, R4.1, U1.3
unnamed: R9.2, U2.1

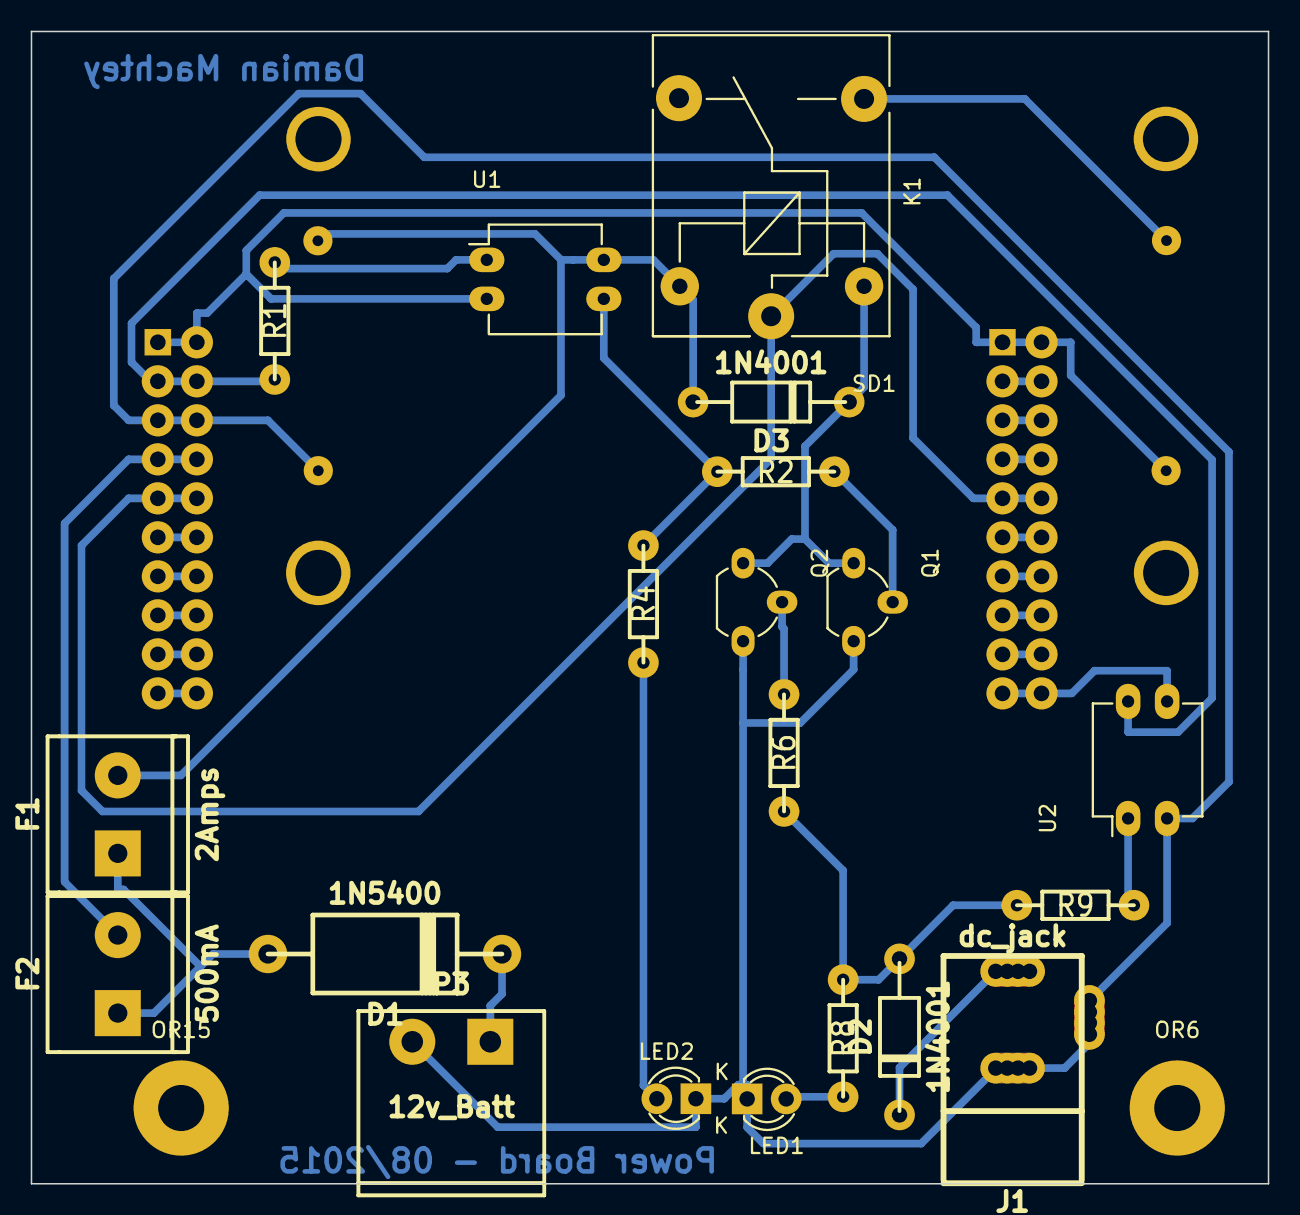
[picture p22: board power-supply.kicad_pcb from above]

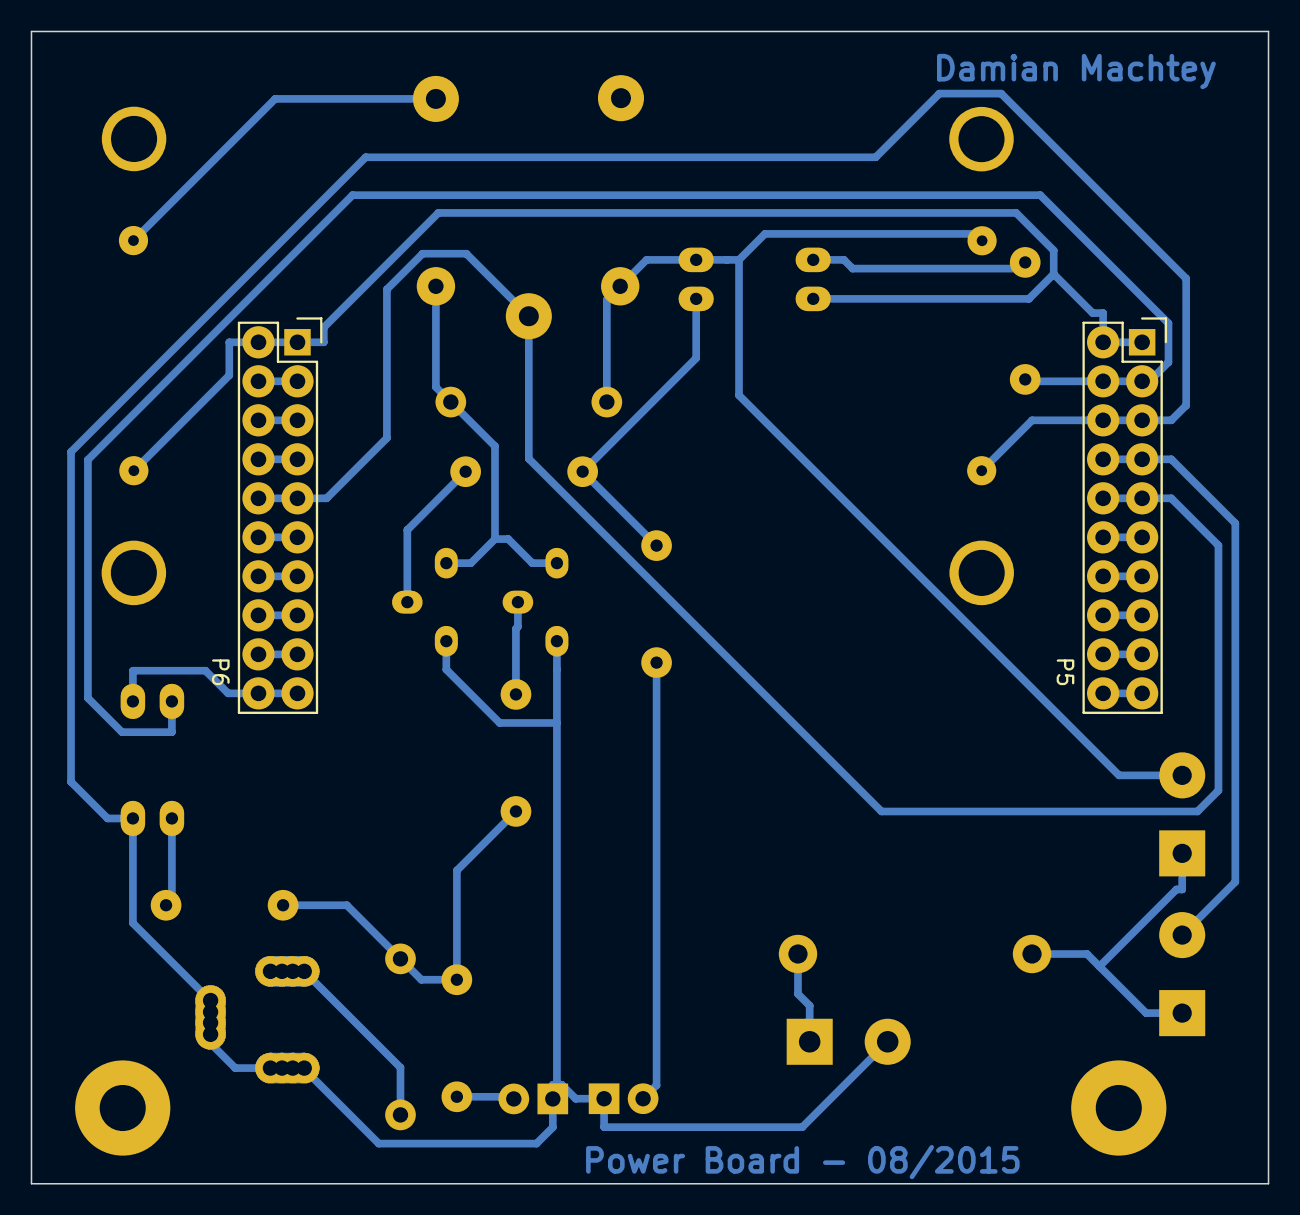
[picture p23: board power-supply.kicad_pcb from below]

Board: 2 copper layers, 80.5 x 75.0 mm, 25 parts (2 on the bottom side), 32 nets.

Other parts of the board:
OR6, OR15: Fix Hole; SolderWirePad_single_2-5mmDrill

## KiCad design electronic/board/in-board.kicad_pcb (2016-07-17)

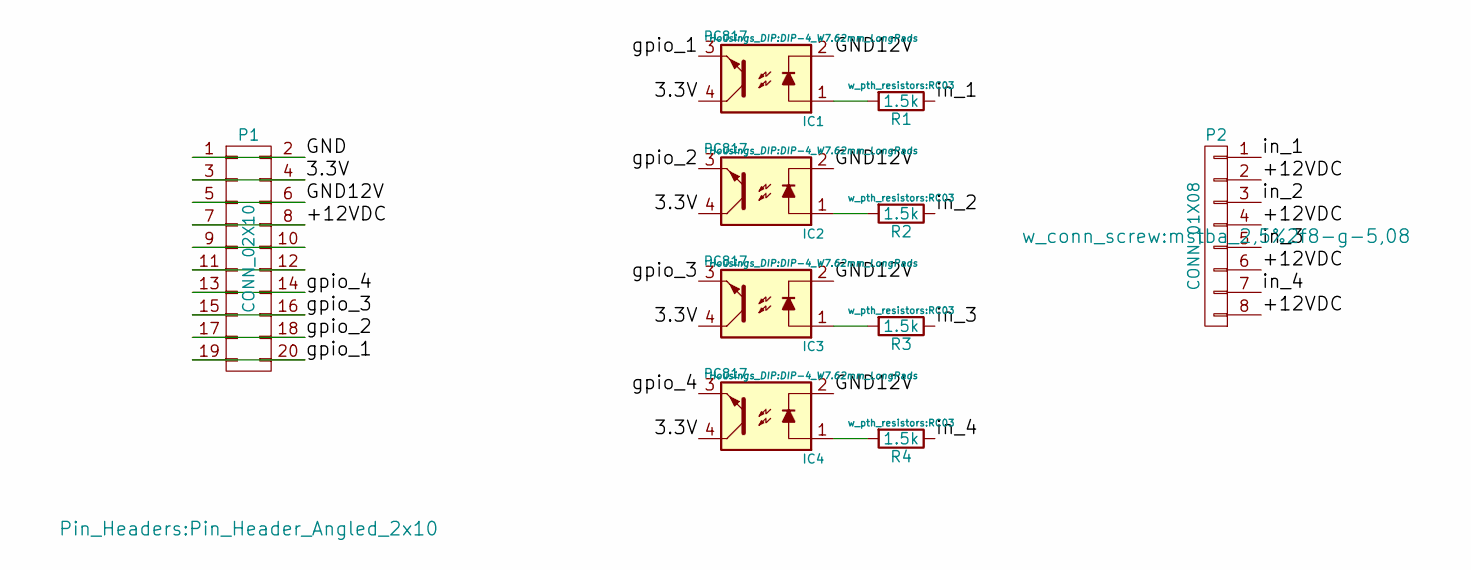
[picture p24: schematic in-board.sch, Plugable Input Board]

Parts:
IC1, IC2, IC3, IC4: PC817; DIP-4_W7.62mm_LongPads
P1: CONN_02X10; Pin_Header_Angled_2x10
P2: CONN_01X08; mstba_2,5%2f8-g-5,08
R1, R2, R3, R4: 1.5k; RC03

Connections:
/3.3V: IC1.4, IC2.4, IC3.4, IC4.4, P1.3, P1.4
/+12VDC: P1.7, P1.8, P2.2, P2.4, P2.6, P2.8
/GND: P1.1, P1.2
/GND12V: IC1.2, IC2.2, IC3.2, IC4.2, P1.5, P1.6
/gpio_1: IC1.3, P1.19, P1.20
/gpio_2: IC2.3, P1.17, P1.18
/gpio_3: IC3.3, P1.15, P1.16
/gpio_4: IC4.3, P1.13, P1.14
/in_1: P2.1, R1.1
/in_2: P2.3, R2.1
/in_3: P2.5, R3.1
/in_4: P2.7, R4.1
unnamed: IC1.1, R1.2
unnamed: IC2.1, R2.2
unnamed: IC3.1, R3.2
unnamed: IC4.1, R4.2
unnamed: P1.9, P1.10
unnamed: P1.11, P1.12

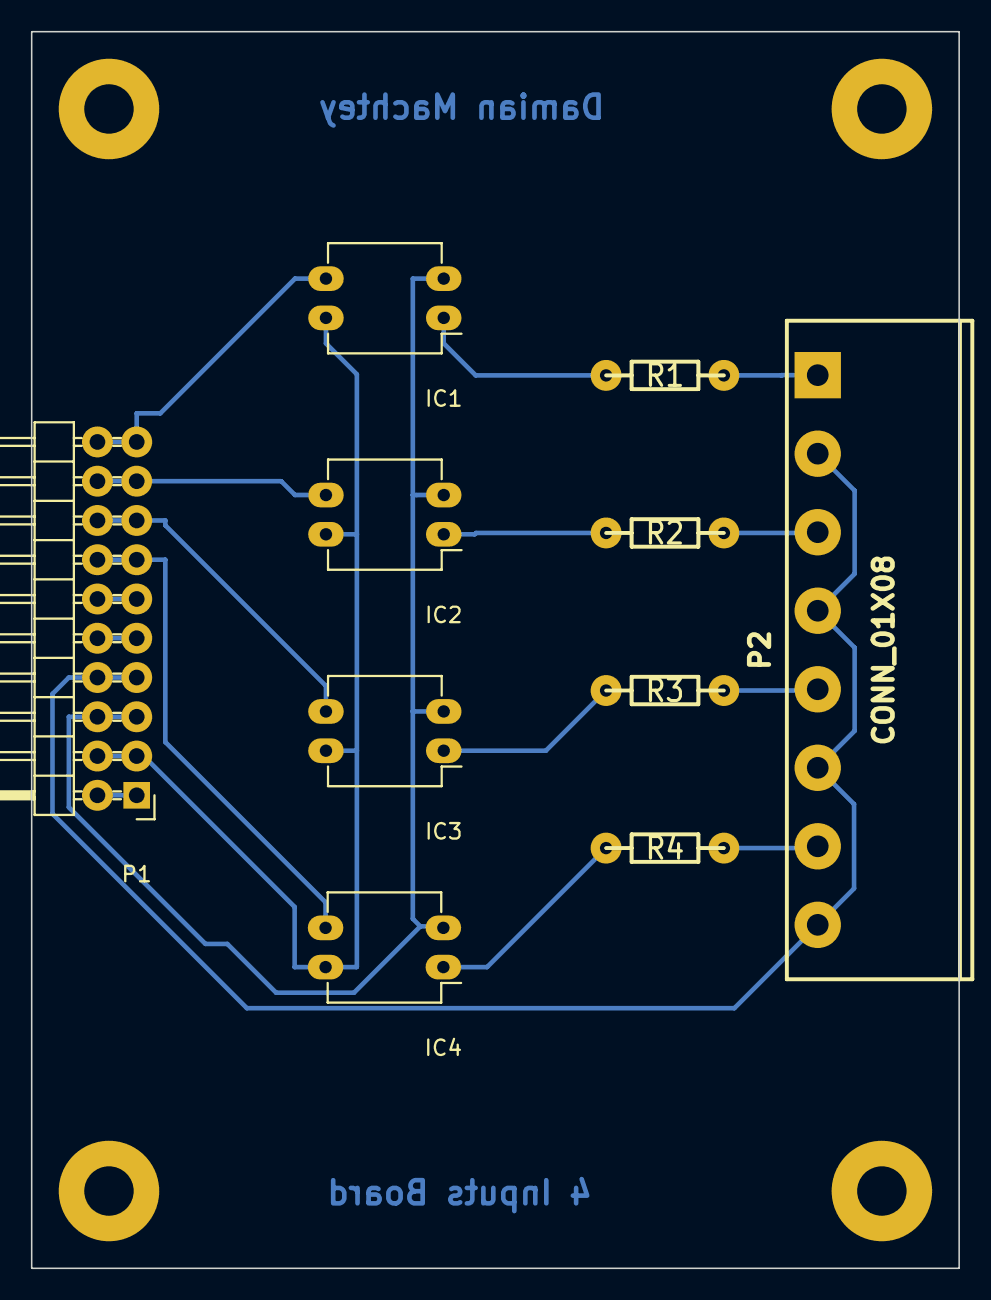
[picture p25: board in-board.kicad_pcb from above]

Board: 2 copper layers, 60.0 x 80.0 mm, 14 parts (0 on the bottom side), 18 nets.

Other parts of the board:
OR1, OR2, OR3, OR4: SolderWirePad_single_2-5mmDrill

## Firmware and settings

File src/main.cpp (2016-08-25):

// Filename: main.cpp
//
// Description:
// Author: Damian Machtey
// Maintainer:
//
// Created: Mon Jul 25 11:44:00 2016 (-0500)
//
// Last-Updated: Wed Aug 24 17:35:59 2016 (-0300)
//           By: Damian Machtey
//     Update #: 189

// Change Log:
//
//
// Copyright (C) 2016 Damian Machtey
//
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
//

// Code:


#include <iostream>
//#include <time.h>
//#include <unistd.h> //for usleep
#include <chrono>
#include <thread>
#include <csignal>

#include "mosquittopp.h"

#include "coil.h"
#include "dimmer.h"
#include "domtypes.h"
#include "pru_data.hp"
#include "lapse.h"
#include "temperature.h"
#include "pru_loader.h"
#include "gpio.h"

int finish_signal = 0;
void signal_handler(int signal){
  finish_signal = 1;
}

using namespace lighting;
bool COIL::master_set = false;

int main(int argc, char *argv[])
{

  D("DELAY_INS = " << DELAY_INS << std::endl;)
    if(DELAY_INS < 0){
      std::cerr << "Error: there is a miss configuration on PRUS DELAY_INS, its < 0\n";
      exit(EXIT_FAILURE);
    }

  // initialize random seed:
  srand (time(NULL));
  // initialize mosquittopp
  mosqpp::lib_init();


  // Configure and load pruss program
  PRULOADER pru_0("/usr/lib/domotics/pwm.bin", zero);


  // Inputs declaration
  exploringBB::GPIO SW1(4);   // patio
  exploringBB::GPIO SW2(51);  // salon
  exploringBB::GPIO SW3(50);  // ingreso
  exploringBB::GPIO SW4(60);  // baño
  exploringBB::GPIO SW5(115); // Cocina
  exploringBB::GPIO BELL(14); // Timbre
  exploringBB::GPIO door(111); // DOOR opener. Sloot 15,1


  SW1.setDirection(exploringBB::INPUT);
  SW2.setDirection(exploringBB::INPUT);
  SW3.setDirection(exploringBB::INPUT);
  SW4.setDirection(exploringBB::INPUT);
  SW5.setDirection(exploringBB::INPUT);
  BELL.setDirection(exploringBB::INPUT);
  door.setDirection(exploringBB::OUTPUT);


  // Outputs declaration
  DIMMER patio  ("LT1", "localhost", 1883, 18*4, 100, GPIO0_27_SP, &pru_0);  // Patio
  DIMMER salon  ("LT2", "localhost", 1883, 18*4, 100, GPIO1_15_SP, &pru_0);  // Salon quincho
  DIMMER ingreso("LT3", "localhost", 1883, 18,   100, GPIO0_22_SP, &pru_0);  // Ingreso quincho
  DIMMER bano   ("LT4", "localhost", 1883, 18,   70,  GPIO1_30_SP, &pru_0);  // Baño
  DIMMER cocina ("LT5", "localhost", 1883, 18,   90,  GPIO1_4_SP,  &pru_0);  // Cocina quincho
  COIL  opendoor("door","localhost", 1883, 0.2);


  TEMPERATURE T1("CPUTemp", "localhost", 1883,
                 "/sys/devices/ocp.3/44e10448.bandgap/temp1_input", 60000);

  lighting::time_t scan_time;
  bool bell_sw = false;
  LAPSE lapse;
  do{
      scan_time = lapse.get_lapse();

      bell_sw = BELL.getValue();


      // patio, Slot 10.2
      patio.looop(scan_time, SW1.getValue(), bell_sw);

      // salon Slot 10.1
      salon.looop(scan_time, SW2.getValue(), bell_sw);

      // Ingreso Slot 10.3
      ingreso.looop(scan_time, SW3.getValue(), bell_sw);

      // baño Slot 10.4
      bano.looop(scan_time, SW4.getValue(), bell_sw);

      // cocina Slot 9.1
      cocina.looop(scan_time, SW5.getValue(), bell_sw);

      // Door
      door.setValue(opendoor.looop(scan_time, false)? exploringBB::HIGH : exploringBB::LOW);


      T1.looop(scan_time);

      std::this_thread::sleep_for(std::chrono::milliseconds(4));

      signal(SIGINT, signal_handler);
      if (finish_signal)
        break;
    }while(true);

  mosqpp::lib_cleanup(); // DIMMERS and TEMPERATURES get destroyed here
  pru_0.~PRULOADER();
  std::cout << "We've cleaned all up" << std::endl;
  return 0;
}
//
// main.cpp ends here

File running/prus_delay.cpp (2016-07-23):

// Filename: prus_delay.cpp
// 
// Description: 
// Author: Damian Machtey
// Maintainer: 
// 
// Created: 2015-06-22 Mon 
// 
// Last-Updated: Sat Jul 23 12:43:51 2016 (-0500)
//           By: Damian Machtey
//     Update #: 2

// Change Log:
// 
// 
// Copyright (C) 2016 Damian Machtey
// 
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
// 

// Code:



#include <iostream>

#define LOOPCOUNTER  100
#define INS_PER_US   200         // 5ns per instruction
#define INS_PER_DELAY_LOOP 2     // two instructions per delay loop

#define INS_PER_GPIO 12
#define TARGET_HZ 1333
#define N_GPIOS 33
#define TARGET_LOOP_TIME (1000000 / TARGET_HZ)  // us that should last each main loop

#define INS_OVERHEAD 4


// DELAY_INS = (TargetTimePerLoop - Needed Time per Loop)/LoopCounter


#define DELAY_T_USED ((INS_PER_GPIO * N_GPIOS + INS_OVERHEAD) * LOOPCOUNTER)/INS_PER_US // time us consumed by program

#define DELAY_T  (TARGET_LOOP_TIME - DELAY_T_USED)

#define DELAY_INS ((DELAY_T * INS_PER_US) / (LOOPCOUNTER * INS_PER_DELAY_LOOP))


using namespace std;

int main(int argc, char *argv[])
{
  cout << endl;
  cout << "Loopcounter/duty points: " << LOOPCOUNTER << endl;
  cout << "Target frequency: " << TARGET_HZ << " Hz" <<  endl << endl;


  cout << "Target loop time: " << TARGET_LOOP_TIME << " us" << endl;
  cout << "Delay time: " << DELAY_T << " us" << endl;
  cout << "Delay inst: " <<  DELAY_INS << endl;
  cout << "Max frequency: " << 1e6*INS_PER_US/((INS_PER_GPIO * N_GPIOS + INS_OVERHEAD) * LOOPCOUNTER) << " Hz" << endl;

  return 0;
}

// 
// prus_delay.cpp ends here

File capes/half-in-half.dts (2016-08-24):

// Copyright 2013
// Charles Steinkuehler <charles@steinkuehler.net>
//
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
// Modified by Damian Machtey 2015-07-02 Thu
// For home automation with Beaglebone black

/dts-v1/;
/plugin/;

/ {
    compatible = "ti,beaglebone", "ti,beaglebone-black";

    /* identification */
    part-number = "half-in-half";
    version = "00A0";

    /* state the resources this cape uses */
    exclusive-use =
    /*      "P8.1",     GND     */
    /*      "P8.2",     GND     */
    "P8.3",     /* emmc    */
    "P8.4",     /* emmc    */
    "P8.5",     /* emmc    */
    "P8.6",     /* emmc    */
    "P8.7",
    "P8.8",
    "P8.9",
    "P8.10",
    "P8.11",
    "P8.12",
    "P8.13",
    "P8.14",
    "P8.15",
    "P8.16",
    "P8.17",
    "P8.18",
    "P8.19",
    "P8.20",    /* emmc    */
    "P8.21",    /* emmc    */
    "P8.22",    /* emmc    */
    "P8.23",    /* emmc    */
    "P8.24",    /* emmc    */
    "P8.25",    /* emmc    */
    "P8.26",
    "P8.27",    /* hdmi    */
    "P8.28",    /* hdmi    */
    "P8.29",    /* hdmi    */
    "P8.30",    /* hdmi    */
    "P8.31",    /* hdmi    */
    "P8.32",    /* hdmi    */
    "P8.33",    /* hdmi    */
    "P8.34",    /* hdmi    */
    "P8.35",    /* hdmi    */
    "P8.36",    /* hdmi    */
    "P8.37",    /* hdmi    */
    "P8.38",    /* hdmi    */
    "P8.39",    /* hdmi    */
    "P8.40",    /* hdmi    */
    "P8.41",    /* hdmi    */
    "P8.42",    /* hdmi    */
    "P8.43",    /* hdmi    */
    "P8.44",    /* hdmi    */
    "P8.45",    /* hdmi    */
    "P8.46",    /* hdmi    */
    /*
    * "uart5",    /\* hdmi    *\/
    * "epwmss0",  /\* hdmi    *\/
    * "ehrpwm0",  /\* hdmi    *\/
    * "ecap0",    /\* hdmi    *\/
    * "epwmss1",  /\* hdmi    *\/
    * "ehrpwm1",  /\* hdmi    *\/
    * "epwmss2",  /\* hdmi    *\/
    * "ehrpwm2",  /\* hdmi    *\/
    * "ecap2",    /\* hdmi    *\/
    */

    /*      "P9.1",     GND     */
    /*      "P9.2",     GND     */
    /*      "P9.3",     3.3V    */
    /*      "P9.4",     3.3V    */
    /*      "P9.5",     VDD_5V  */
    /*      "P9.6",     VDD_5V  */
    /*      "P9.7",     SYS_5V  */
    /*      "P9.8",     SYS_5V  */
    /*      "P9.9",     PWR_BUT */
    /*      "P9.10",    RESETn  */
    "P9.11",
    "P9.12",
    "P9.13",
    "P9.14",
    "P9.15",
    "P9.16",
    "P9.17",
    "P9.18",
    /*      "P9.19",    I2C     */
    /*      "P9.20",    I2C     */
    "P9.21",
    "P9.22",
    "P9.23",
    "P9.24",
    "P9.25",
    "P9.26",
    "P9.27",
    "P9.28",
    "P9.29",
    "P9.30",
    "P9.31",
    /*      "P9.32",    VADC    */
    /*      "P9.33",    AIN4    */
    /*      "P9.34",    AGND    */
    /*      "P9.35",    AIN6    */
    /*      "P9.36",    AIN5    */
    /*      "P9.37",    AIN2    */
    /*      "P9.38",    AIN3    */
    /*      "P9.39",    AIN0    */
    /*      "P9.40",    AIN1    */
    "P9.41",
    "P9.41.1",
    "P9.42",
    "P9.42.1",
    /*      "P9.43",    GND     */
    /*      "P9.44",    GND     */
    /*      "P9.45",    GND     */
    /*      "P9.46",    GND     */

    /*
    * "uart1",
    * "uart2",
    * "uart4",
    */
    //      "uart5",    /* Conflicts with HDMI  */

    /*
    * "ehrpwm0A",
    * "ehrpwm0B",
    * "ehrpwm1A",
    * "ehrpwm1B",
    * "ehrpwm2A",
    * "ehrpwm2B",
    */

    //        "epwmss0",
    //        "ehrpwm0",
    //        "ecap0",
    //        "epwmss1",
    //        "ehrpwm1",
    //        "epwmss2",
    //        "ehrpwm2",
    //        "ecap2",

    /*
    * "i2c1",
    * "spi1",
    * "spi0",
    * "dcan0",
    * "dcan1",
    */

    "pru0",
    "pru1",
    "pruss";

    fragment@0 {
        target = <&am33xx_pinmux>;
        __overlay__ {
            gpio_pins: pinmux_gpio_pins {         // The GPIO pins
                pinctrl-single,pins = <
                0x018  0x07        // P8_03 MODE7 | OUTPUT | GPIO pull-down GPIO_38
                0x01c  0x07        // P8_04 MODE7 | OUTPUT | GPIO pull-down GPIO_39
                0x008  0x07        // P8_05 MODE7 | OUTPUT | GPIO pull-down GPIO_34
                0x00c  0x07        // P8_06 MODE7 | OUTPUT | GPIO pull-down GPIO_35
                0x090  0x07        // P8_07 MODE7 | OUTPUT | GPIO pull-down GPIO_66
                0x094  0x07        // P8_08 MODE7 | OUTPUT | GPIO pull-down GPIO_67
                0x09c  0x07        // P8_09 MODE7 | OUTPUT | GPIO pull-down GPIO_69
                0x098  0x07        // P8_10 MODE7 | OUTPUT | GPIO pull-down GPIO_68
                0x034  0x07        // P8_11 MODE7 | OUTPUT | GPIO pull-down GPIO_45
                0x030  0x07        // P8_12 MODE7 | OUTPUT | GPIO pull-down GPIO_44
                0x024  0x07        // P8_13 MODE7 | OUTPUT | GPIO pull-down GPIO_23
                0x028  0x07        // P8_14 MODE7 | OUTPUT | GPIO pull-down GPIO_26
                0x03c  0x07        // P8_15 MODE7 | OUTPUT | GPIO pull-down GPIO_47
                0x038  0x07        // P8_16 MODE7 | OUTPUT | GPIO pull-down GPIO_46
                0x02c  0x07        // P8_17 MODE7 | OUTPUT | GPIO pull-down GPIO_27
                0x08c  0x07        // P8_18 MODE7 | OUTPUT | GPIO pull-down GPIO_65
                0x020  0x07        // P8_19 MODE7 | OUTPUT | GPIO pull-down GPIO_22
                0x084  0x07        // P8_20 MODE7 | OUTPUT | GPIO pull-down GPIO_63
                0x080  0x07        // P8_21 MODE7 | OUTPUT | GPIO pull-down GPIO_62
                0x014  0x07        // P8_22 MODE7 | OUTPUT | GPIO pull-down GPIO_37
                0x010  0x07        // P8_23 MODE7 | OUTPUT | GPIO pull-down GPIO_36
                0x004  0x07        // P8_24 MODE7 | OUTPUT | GPIO pull-down GPIO_33
                0x000  0x07        // P8_25 MODE7 | OUTPUT | GPIO pull-down GPIO_32
                0x07c  0x07        // P8_26 MODE7 | OUTPUT | GPIO pull-down GPIO_61
                0x0E0  0x07        // P8_27 MODE7 | OUTPUT | GPIO pull-down GPIO_86
                0x0E8  0x07        // P8_28 MODE7 | OUTPUT | GPIO pull-down GPIO_88
                0x0E4  0x07        // P8_29 MODE7 | OUTPUT | GPIO pull-down GPIO_87
                0x0EC  0x07        // P8_30 MODE7 | OUTPUT | GPIO pull-down GPIO_89
                0x0D8  0x07        // P8_31 MODE7 | OUTPUT | GPIO pull-down GPIO_10
                0x0DC  0x07        // P8_32 MODE7 | OUTPUT | GPIO pull-down GPIO_11
                0x0D4  0x07        // P8_33 MODE7 | OUTPUT | GPIO pull-down GPIO_9
                0x0CC  0x07        // P8_34 MODE7 | OUTPUT | GPIO pull-down GPIO_81
                0x0D0  0x07        // P8_35 MODE7 | OUTPUT | GPIO pull-down GPIO_8
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

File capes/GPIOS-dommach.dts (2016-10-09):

/* Filename: GPIOS-dommach.dts
*
* Description:
* Author: Damian Machtey
* Maintainer:
*
* Created: Wed Sep 21 07:56:37 2016 (-0300)
*
* Last-Updated: Thu Sep 22 12:08:59 2016 (-0300)
*           By: Damian Machtey
*     Update #: 9

* Change Log:
*

* Copyright (C) 2016 Damian Machtey

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
* You should have received a copy of the GNU General Public License
* along with GNU Emacs.  If not, see <http://www.gnu.org/licenses/>.
*/

/* Code: */

/dts-v1/;
/plugin/;

/{
    compatible = "ti,beaglebone", "ti,beaglebone-black";
    part-number = "GPIOS-dommach";
    version = "00A0";

    fragment@0 {
        target = <&am33xx_pinmux>;

        __overlay__ {
            gpios: GPIOS-dommach {
			    pinctrl-single,pins = <

                /* OUTPUT  GPIO(mode7) 0x07 pulldown, 0x17 pullup, 0x?f no pullup/down */
			    /* INPUT   GPIO(mode7) 0x27 pulldown, 0x37 pullup, 0x?f no pullup/down */
        //| Address | Mode | BBB Port | gpio number |  Slot | Order | Mode 7   | Mode  | Mode | Comment |
        //|---------+------+----------+-------------+-------+-------+----------+-------+------+---------|
                0x164  0x27  // P9_42 |           7 | Power |       | GPIO0_7  |       |      | Mains   |

                0x0D8  0x07  // P8_31 |          10 |     0 |     1 | GPIO0_10 |       |      |         |
                0x0D4  0x07  // P8_33 |           9 |     0 |     2 | GPIO0_9  |       |      |         |
                0x0D0  0x07  // P8_35 |           8 |     0 |     3 | GPIO0_8  |       |      |         |
                0x0C0  0x27  // P8_37 |          78 |     0 |     4 | GPIO2_14 |       |      |         |

                0x0B8  0x27  // P8_39 |          76 |     1 |     1 | GPIO2_12 |       |      |         |
                0x0B0  0x27  // P8_41 |          74 |     1 |     2 | GPIO2_10 |       |      |         |
                0x0A8  0x27  // P8_43 |          72 |     1 |     3 | GPIO2_8  |       |      |         |
                0x0A0  0x27  // P8_45 |          70 |     1 |     4 | GPIO2_6  |       |      |         |

                0x0A4  0x27  // P8_46 |          71 |     2 |     1 | GPIO2_7  |       |      |         |
                0x0AC  0x27  // P8_44 |          73 |     2 |     2 | GPIO2_9  |       |      |         |
                0x0B4  0x27  // P8_42 |          75 |     2 |     3 | GPIO2_11 |       |      |         |
                0x0BC  0x27  // P8_40 |          77 |     2 |     4 | GPIO2_13 |       |      |         |

                0x0C4  0x27  // P8_38 |          79 |     3 |     1 | GPIO2_15 |       |      |         |
                0x0C8  0x27  // P8_36 |          80 |     3 |     2 | GPIO2_16 |       |      |         |
                0x0CC  0x07  // P8_34 |          81 |     3 |     3 | GPIO2_17 |       |      |         |
                0x0DC  0x07  // P8_32 |          11 |     3 |     4 | GPIO0_11 |       |      |         |

                0x090  0x07  // P8_07 |          66 |     4 |     1 | GPIO2_2  |       |      |         |
                0x09c  0x07  // P8_09 |          69 |     4 |     2 | GPIO2_5  |       |      |         |
                0x034  0x07  // P8_11 |          45 |     4 |     3 | GPIO1_13 |       |      |         |
                0x024  0x07  // P8_13 |          23 |     4 |     4 | GPIO0_23 |       |      |         |

                0x00c  0x07  // P8_06 |          35 |     5 |     1 | GPIO1_3  |       |      |         |
                0x01c  0x07  // P8_04 |          39 |     5 |     2 | GPIO1_7  |       |      |         |
                0x018  0x07  // P8_03 |          38 |     5 |     3 | GPIO1_6  |       |      |         |
                0x008  0x07  // P8_05 |          34 |     5 |     4 | GPIO1_2  |       |      |         |

                0x028  0x07  // P8_14 |          26 |     6 |     1 | GPIO0_26 |       |      |         |
                0x030  0x07  // P8_12 |          44 |     6 |     2 | GPIO1_12 |       |      |         |
                0x098  0x07  // P8_10 |          68 |     6 |     3 | GPIO2_4  |       |      |         |
                0x094  0x07  // P8_08 |          67 |     6 |     4 | GPIO2_3  |       |      |         |

                0x014  0x07  // P8_22 |          37 |     7 |     1 | GPIO1_5  |       |      |         |
                0x084  0x07  // P8_20 |          63 |     7 |     2 | GPIO1_31 | UART4 |      |         |
                0x08c  0x07  // P8_18 |          65 |     7 |     3 | GPIO2_1  |       |      |         |
                0x038  0x07  // P8_16 |          46 |     7 |     4 | GPIO1_14 |       |      |         |

                0x0EC  0x07  // P8_30 |          89 |     8 |     1 | GPIO2_25 |       |      |         |
                0x0E8  0x07  // P8_28 |          88 |     8 |     2 | GPIO2_24 |       |      |         |
                0x07c  0x07  // P8_26 |          61 |     8 |     3 | GPIO1_29 |       |      |         |
                0x004  0x07  // P8_24 |          33 |     8 |     4 | GPIO1_1  |       |      |         |

                0x010  0x07  // P8_23 |          36 |     9 |     1 | GPIO1_4  |       |      |         |
                0x000  0x07  // P8_25 |          32 |     9 |     2 | GPIO1_0  |       |      |         |
                0x0E0  0x07  // P8_27 |          86 |     9 |     3 | GPIO2_22 |       |      |         |
                0x0E4  0x07  // P8_29 |          87 |     9 |     4 | GPIO2_23 |       |      |         |

                0x03c  0x07  // P8_15 |          47 |    10 |     1 | GPIO1_15 |       |      |         |
                0x02c  0x07  // P8_17 |          27 |    10 |     2 | GPIO0_27 |       |      |         |
                0x020  0x07  // P8_19 |          22 |    10 |     3 | GPIO0_22 |       |      |         |
                0x080  0x07  // P8_21 |          62 |    10 |     4 | GPIO1_30 | UART4 |      |         |

                0x158  0x27  // P9_18 |           4 |    11 |     1 | GPIO0_4  | I2C1  |      |         |
                0x04c  0x27  // P9_16 |          51 |    11 |     2 | GPIO1_19 |       |      |         |
                0x048  0x27  // P9_14 |          50 |    11 |     3 | GPIO1_18 |       |      |         |
                0x078  0x27  // P9_12 |          60 |    11 |     4 | GPIO1_28 |       |      |         |

                0x1a4  0x27  // P9_27 |         115 |    12 |     1 | GPIO3_1  |       |      |         |
                0x180  0x27  // P9_26 |          14 |    12 |     2 | GPIO0_14 | UART1 | I2C1 |         |
                0x184  0x27  // P9_24 |          15 |    12 |     3 | GPIO0_15 | UART1 | I2C1 |         |
                0x150  0x27  // P9_22 |           2 |    12 |     4 | GPIO0_2  | UART2 | I2C2 |         |
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

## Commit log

2016-08-03 temperature added
2016-08-09 Makefile, a correction on pwm.p
    [main.cpp]
2016-08-14 going on/off threaded, almost done
2016-08-15 Threads corrected
2016-08-24 Some hw, +others
    [base-board-arranged.dsn, base-board-arranged.kicad_pcb, base-board-arranged.sch]
2016-08-25 Main Board
    [base-board-arranged-freeroute.dsn, base-board-arranged.dsn, base-board-arranged.kicad_pcb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]
2016-08-26 Main board, IOs gated
    [base-board-arranged.kicad_pcb, base-board-arranged.sch]
2016-09-12 3d models - enclosure them
    [in_board.FCStd, out_board.FCStd, relay_board.FCStd]
2017-06-30 License statement error corrected
    [pru_loader.cpp]

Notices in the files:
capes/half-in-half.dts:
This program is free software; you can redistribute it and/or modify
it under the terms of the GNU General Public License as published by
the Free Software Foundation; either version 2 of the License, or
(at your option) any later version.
